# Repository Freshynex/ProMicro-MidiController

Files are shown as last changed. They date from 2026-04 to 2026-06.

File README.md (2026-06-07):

# Pro Micro Midi Controller

## 1. A projekt bemutatása
### 1.1 Általános leírás
Ez a projekt a zenekészítés/zeneszerzés folyamatát segíti a MIDI protokoll felhasználásával.
Ennek a készüléknek a felépítése különböző feladatott ellátó alrészekből áll.

### 1.2 Vezérlő és modulok



A legfőbb része egy Atmel ATMEGA32u4 ic-vel ellátott Arduino Pro Micro fejlesztői alaplap (továbbiakban MCU).
Az MCU-t egy kifejtő-kártyára helyezve a többi alrész (továbbiakban modul) ráköthető.

A kifejtőkártya:

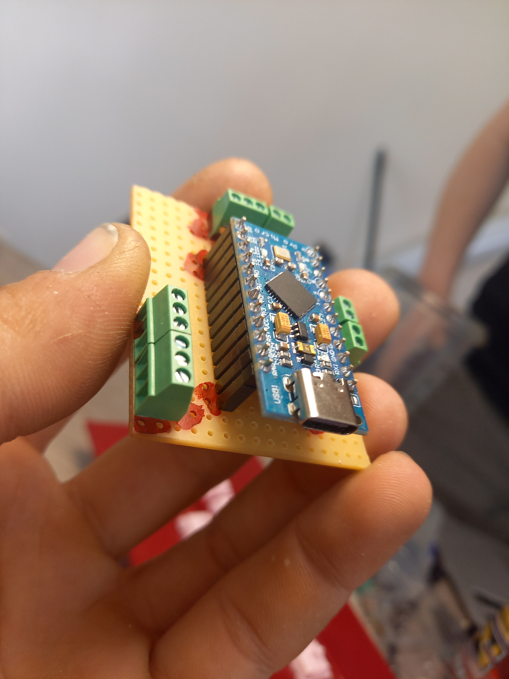
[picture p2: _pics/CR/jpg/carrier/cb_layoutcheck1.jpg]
carrier board


A következő modulok vannak integrálva a készülékben:

 - Kijelző modul (továbbiakban <b>DISP</b>), amely egy egyszerű interfészt biztosít, hogy az aktuális bemeneti
értékeket visszaadja, illetve hogy kényelmesen lehessen konfigurálni azt.

 - Oktáv-váltó modul (továbbiakban <b>OCTSTP</b>), amely egyszerű elérhetőséget ad oktáv-léptetéshez
  
 - Analóg modul (továbbiakban <b>ANAL</b>), egy olyan felület amely kihasználja az MCU saját analog bemeneteit, és
visszaad egy értéket.

 - Billentyűzet modul (továbbiakban <b>KB</b>), amely egy 2 oktávos zongora interfészt ad a felhasználónak. 

## 2. Alkatrészek és kapcsolás

### 2.1 Főalkatrészek

MCU: Arduino Pro Micro Atmel ATMEGA32u4

DISP: 128x64 i2c oled display (SSD1306 driver)

Oktáv váltó gombok: TACTS-6x6x7.3 (2 db)

KB gombok: AKKO Stellar Rose Switch – Lubed-5pin (24 db)

Tengelyes potméter: POM1615 LIN 1K B (2 db)

Toló potméter: PTA2043-2015CIB203 (2 db)

PISO shift register: 74HC166 (3 db)

### 2.1 Kapcsolás rajz

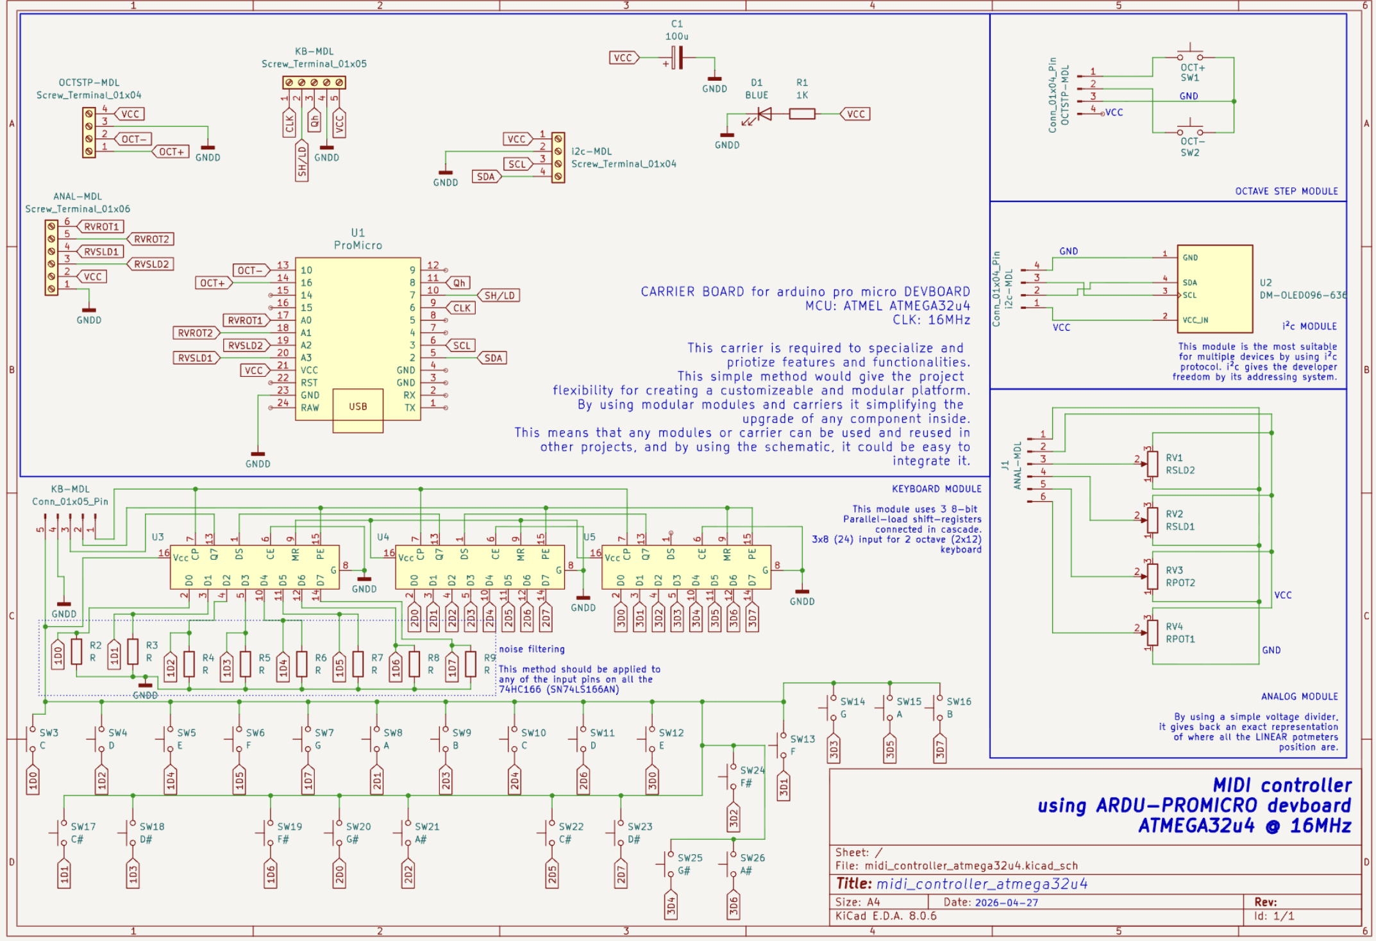
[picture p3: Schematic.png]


## 3. Funkcionalitás
 Teszteléshez használt szoftver: FL Studio 20 (Macbook M1-en kicsit bugos, ezért a kép villódzik néha)

### 3.1 MIDI Protokoll

A MIDI protokollban 8 bites adatcsomagokkal dolgozunk. Két féle üzenet van: status és data. Az első bit azt jelöli, hogy a kettő közül melyiket küldjük, így adat üzenet esetén 0-127, command üzenet esetén 128-255 a használható értéktartomány. Ezek együttesen alkotnak egy midi üzenetet (message).

Egy üzenet mindig status byte-tal kezdődik, amit a parancs függvényében 0, 1 vagy 2 data byte követ.
A status byte felső 4 bitje jelöli a kiadott parancsot (aminek az első bitje mindig 1, így az első kódszó decimálisan a 8), a második fele a csatornát jelöli (16 csatornát lehet kezelni, ebben a projektben egynél többre nincs szükségünk).

Számunkra fontosabb status üzenetek:

| Status üzenet  | Üzenet kódja | Adat byte 1 | Adat byte 2 | Adat byte 3 |
| ---  | --- | --- | --- | --- |
| NoteOn | 0x90 | Pitch | Velocity | |
| NoteOff | 0x80 | Pitch | Velocity | |
| Control Change | 0xB0 | CC number | MSB | LSB * | 

 *<sub> Adat byte 3 (LSB) nem kötelező, de 7 helyett 14 bit pontosságu értéket adhatunk meg vele </sub>

### 3.2 Billentyűzet
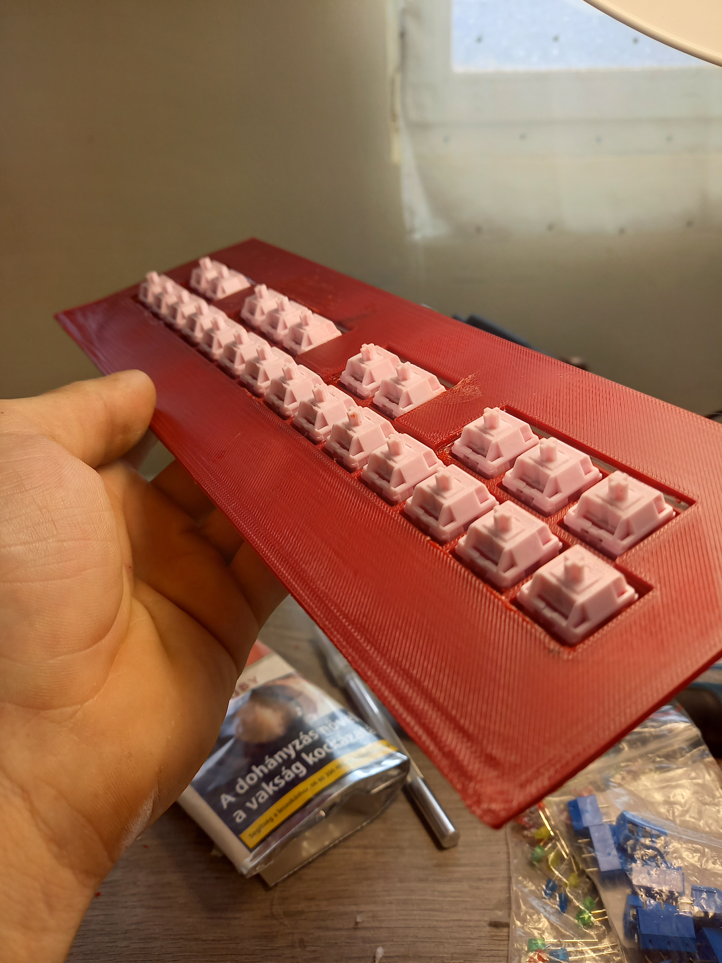
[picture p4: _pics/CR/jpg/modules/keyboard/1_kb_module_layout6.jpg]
Keyboard

A billentyűzet kialakítása egy zongora mintájára készült. 2 oktáv, ami 24 gomb. A gombok mechanikus billentyűkapcsolókkal vannak kivitelezve. A keret illetve gomb kupakok 3D nyomtatással készültek. Három kaszkádolt parallel in serial out shift register segítségével vannak az MCU-ra kötve, így csak 3 pin felhasználása szükséges. Ez a fajta megoldás lehetővé teszi hogy 3Byte-on visszakapjuk a gombok állapotát egyszerre.

### 3.3 Oktáv váltás
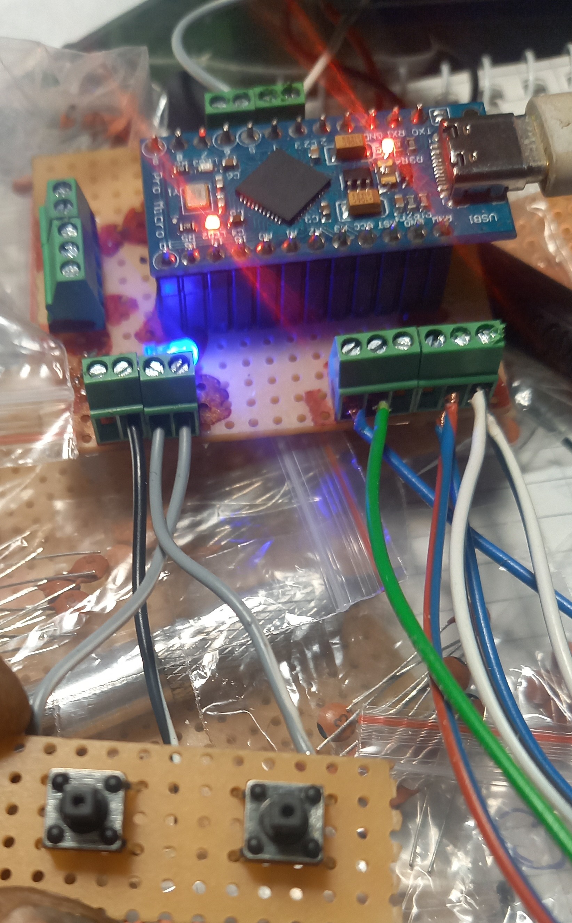
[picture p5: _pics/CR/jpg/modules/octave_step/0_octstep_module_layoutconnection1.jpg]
Octave buttons

A zenekészítéshez szükséges, hogy a billentyűzet képes legyen több oktávon is játszani. Ehhez az <b>MCU</b> két digitális bemenetét használjuk. A készülék oktáv-váltó gombok hatására a billentyűzeten reprezentált 2 oktávot eltolja, és így mind a 10 MIDI protokollban használt oktáv elérhető.

### 3.4 Analog bevitel
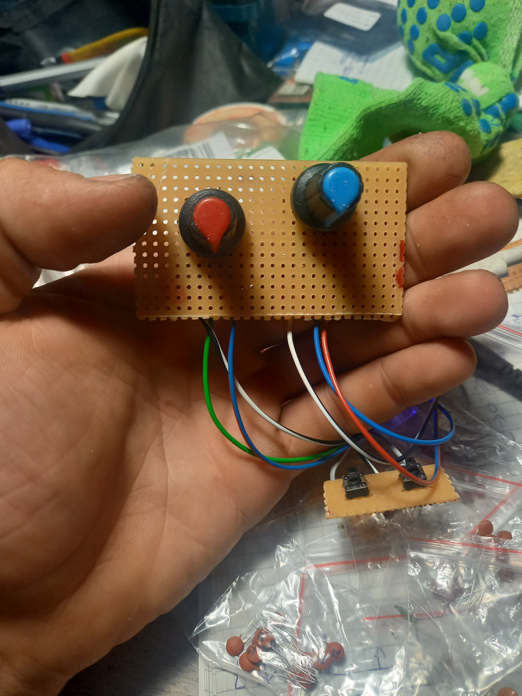
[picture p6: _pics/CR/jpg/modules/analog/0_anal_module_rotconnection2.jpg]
Potmeters

Kettő forgatható és kettő tolható lineáris potméter segítségével, kihasználva Kirchoff törvényeit, képes a készülék adott csatornák állapotait módosítani. A választott <b>MCU</b> analog bemenetei a referencia feszültséghez képest adja vissza a bemeneti értéket. Ezt a készülék 0-1023-as intervallumban elhelyezi (map-eli).

Ez a következő képpen nyílvánul meg:
| Ref. V | ANAL bemenet | Érték |
| ---  | --- | --- |
| 5V | 0V | 0 |
| -"- | 2.5V | 512 |
| -"- | 5V | 1023 |

### 3.5 i²c Kijelző és protokol

Az i²c, egy olyan protokoll, amely MASTER-SLAVE kapcsolatot biztosít <u>kettő vagy több</u> eszköz között. A szállítandó adatot a protokoll címkézi és szállítja az adatvonalon.
Amikor a SLAVE címe egyezik a csomagban elhelyezett célcímmel, akkor azt a SLAVE fogadja és feldogozza. 

A készülék rendelkezik egy kis 1.2"-es OLED kijelző, amely SSD1306-os meghajtású. Jelenleg a <b>DISP</b> beépített címmel rendelkezik, amelynek a módosítása nehézkes.
A mostani címe <b>0x78</b>.

## 4. Bővithetőség
### 4.1 I²C (Inter-Integrated Circuit)

Az <b>MCU</b>-nak nem az összes pin-jét használtuk, ezért ezekre még kapcsolhatóak eszközök. Amennyiben a beépítendő eszköz i²c-vel kommunikál, így az ráközhető párhuzamosan ugyanarra az ágra, amelyiken rajta van a <b>DISP</b>. Ebben az esetben érdemes figyelni a rákötendő eszköz <u><b>címére</b></u>. Amennyiben a címeknél ütközés történik, úgy nem fog működik a ráhelyezett eszköz, illetve a <b>DISP</b>.

Lehetséges bővítési lehetőségek a jelzett protokollon:
| IC / MODUL név | Funkció |
| ---  | --- |
|  ADS1115 / -M  | ANAL bővítő (A0 - A3) |
|PCF8574 / IN830S| DIGITAL bővítő (8db, be) |
|PCF8574 / OC805S| DIGITAL bővítő (8db, ki) |

### 4.2 UART (Universal Asynchronous Receiver-Transmitter)

Az UART egy olyan soron protokoll fajta, amely két egyenrangú eszközt köt össze. Bekötéséhez egy adó, egy fogadó és közös test szükséges. Ez a protokoll a közlendő információt egy start- és stop-bittel ellátott bitfolyammá alakítja.
Ehhez a fajta kapcsolathoz nem szükséges külön órajel, mivel a kommunikációt egy közösen előre deklarált jelaránnyal (baudrate) éri el. A Küldő fél a bitfolyamot a saját Tx (Transmit) ágán küldi a másik eszköz Rx (Receive lábára.
Ez igaz fordítottan is, ezért ez a fajta megoldás Full-Duplex-nek minősül.
| A eszköz | B eszköz |
|---|---|
| Tx | Rx |
| Rx | Tx |
| G | G |
| *Vcc | *Vcc |

*<sub>Ha a másik készülék rendelkezik saját táp-ellátással, akkor a Vcc összekötése nem szükséges.</sub>

## 5. Készülék Prezentáció és Demo

### Billentyűzet
https://github.com/user-attachments/assets/6a722bac-2a85-4638-812b-2556ad7aba79

### Potméter
[<video src="_vids/Pot_demo.mp4" width="320" height="240" controls></video>
](https://github.com/user-attachments/assets/77403d33-6a48-4602-aa05-ce928a655359
)
### Billentyűzet, potméter (pitch paraméter állítása), oktáv váltás
https://github.com/user-attachments/assets/33ad1122-0a03-4d51-aa62-576f443cc43e

### 3D render

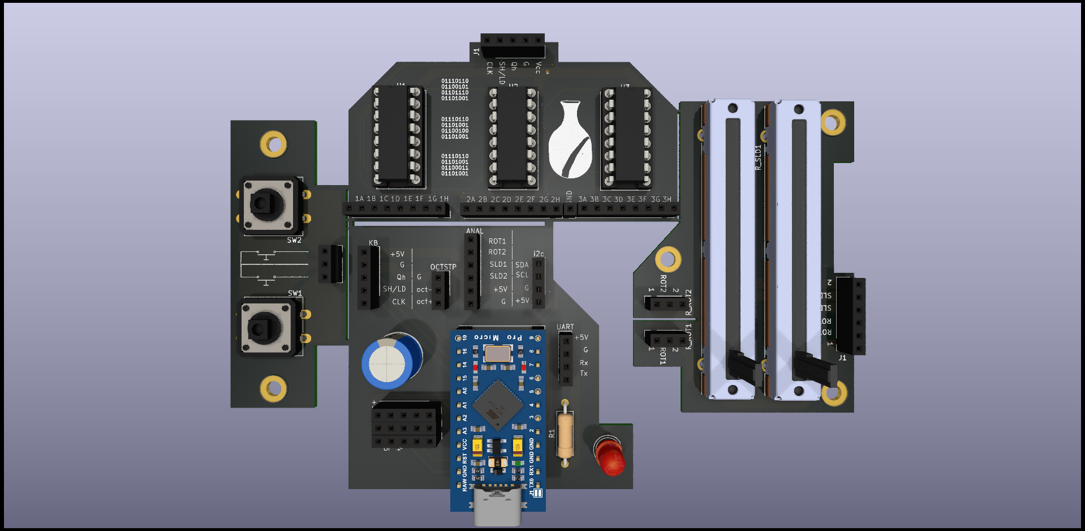
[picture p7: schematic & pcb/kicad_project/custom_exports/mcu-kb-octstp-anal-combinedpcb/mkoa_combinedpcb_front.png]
mkoa_front

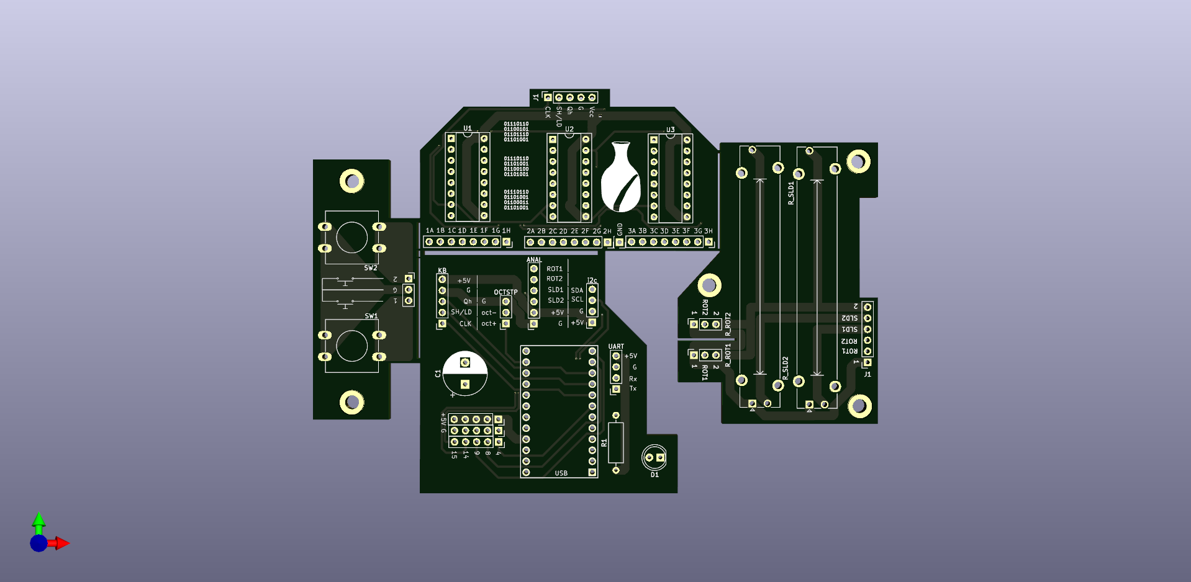
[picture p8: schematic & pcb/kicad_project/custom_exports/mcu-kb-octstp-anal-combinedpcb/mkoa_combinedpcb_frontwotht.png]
mkoa_front2

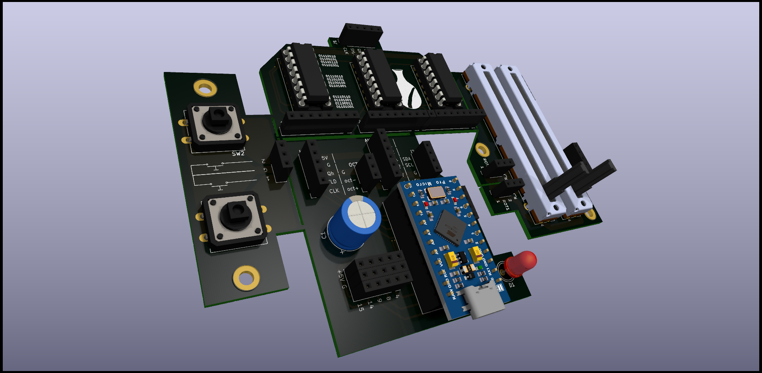
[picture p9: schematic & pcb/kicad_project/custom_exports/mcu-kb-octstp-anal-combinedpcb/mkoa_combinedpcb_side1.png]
mkoa_side1

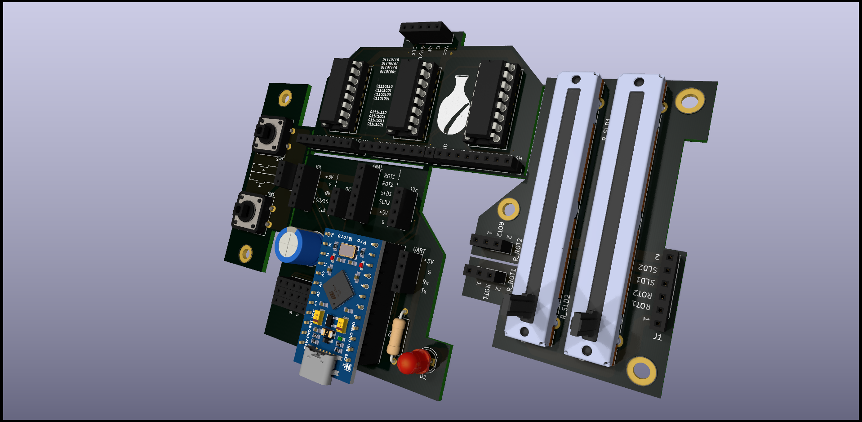
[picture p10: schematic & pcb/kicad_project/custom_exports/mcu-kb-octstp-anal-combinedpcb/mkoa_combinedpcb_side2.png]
mkoa_side2


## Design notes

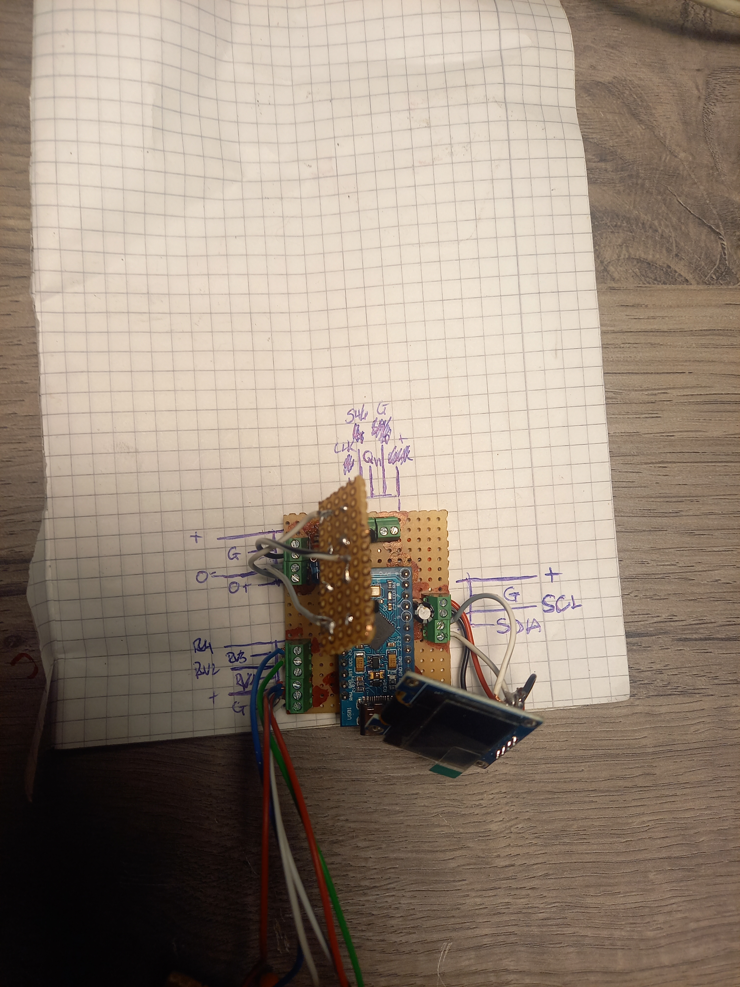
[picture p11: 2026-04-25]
_pics/CR/jpg/carrier/prjct_pinout1.jpg

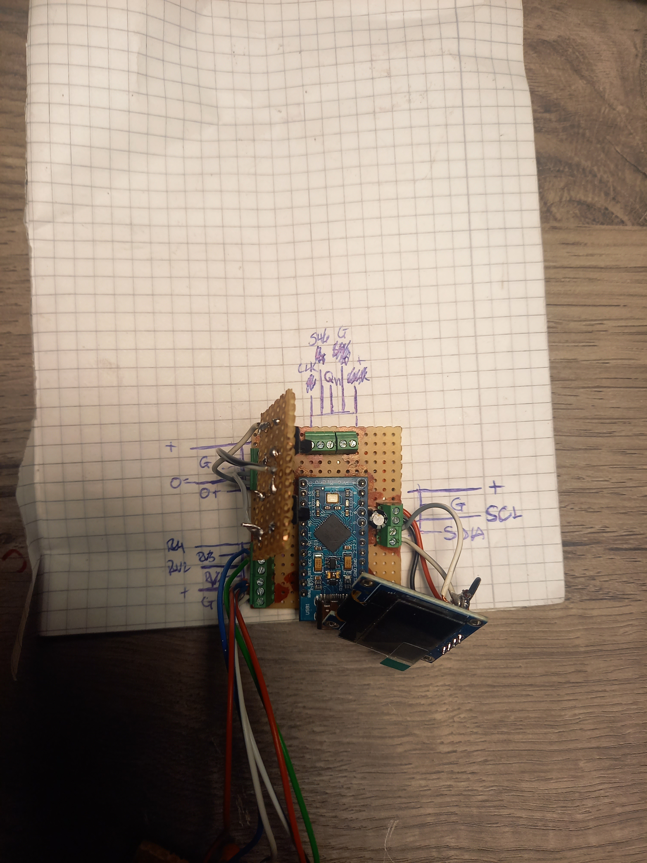
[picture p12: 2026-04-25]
_pics/CR/jpg/carrier/prjct_pinout2.jpg

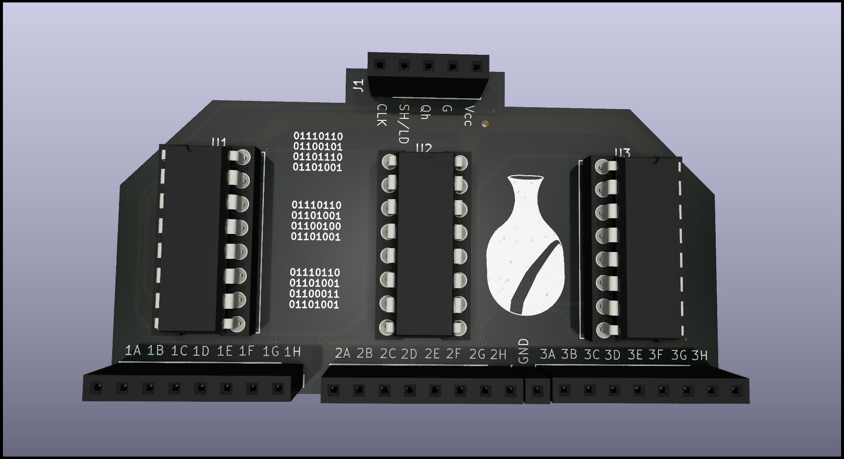
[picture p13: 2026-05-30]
schematic & pcb/exports/kb_3d_3.jpeg

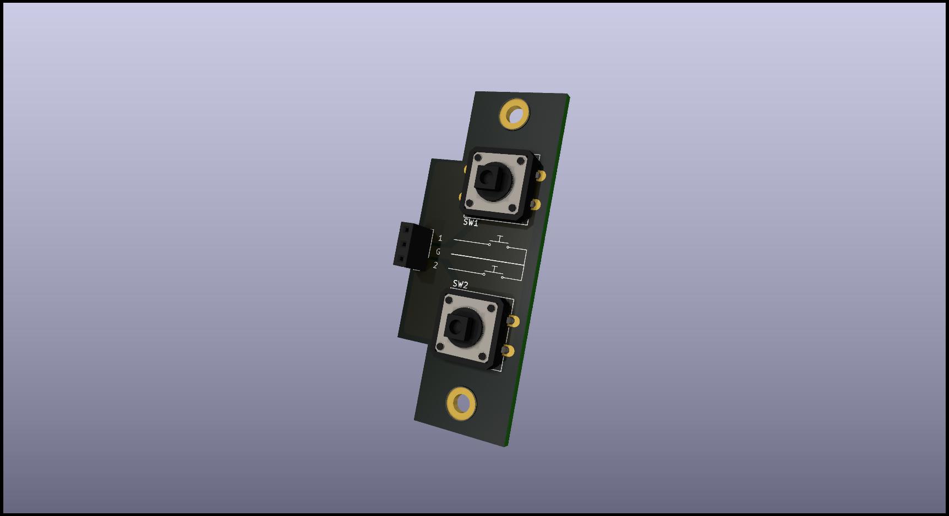
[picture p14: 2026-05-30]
schematic & pcb/exports/octstp_3d_2.jpg

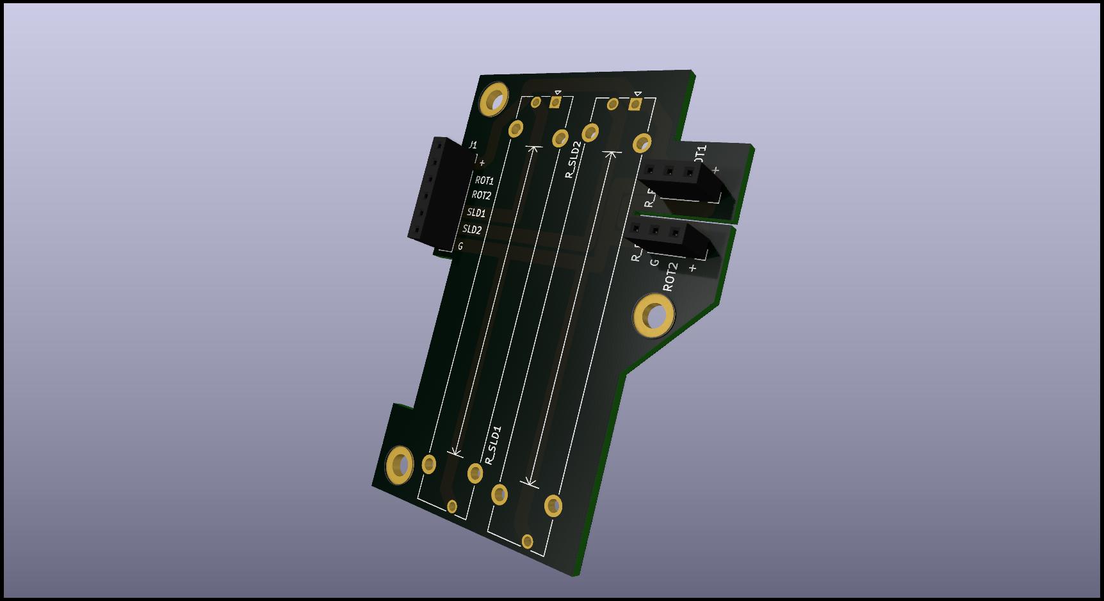
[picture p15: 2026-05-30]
schematic & pcb/exports/anal_3d_2.jpg

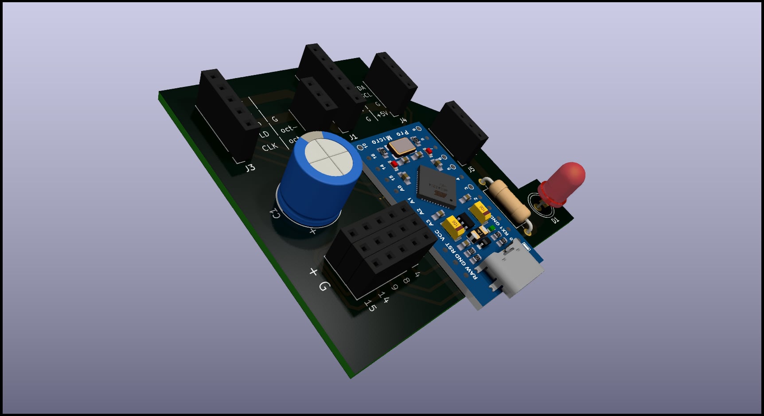
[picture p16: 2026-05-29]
schematic & pcb/exports/carrier_3d_2.jpeg

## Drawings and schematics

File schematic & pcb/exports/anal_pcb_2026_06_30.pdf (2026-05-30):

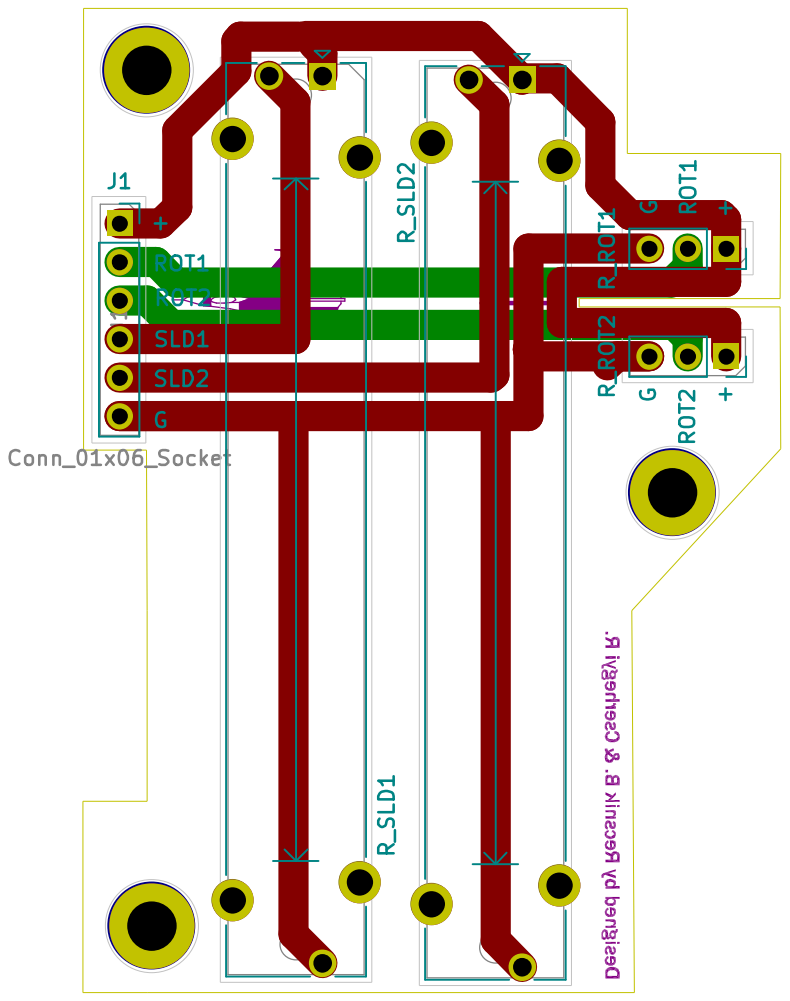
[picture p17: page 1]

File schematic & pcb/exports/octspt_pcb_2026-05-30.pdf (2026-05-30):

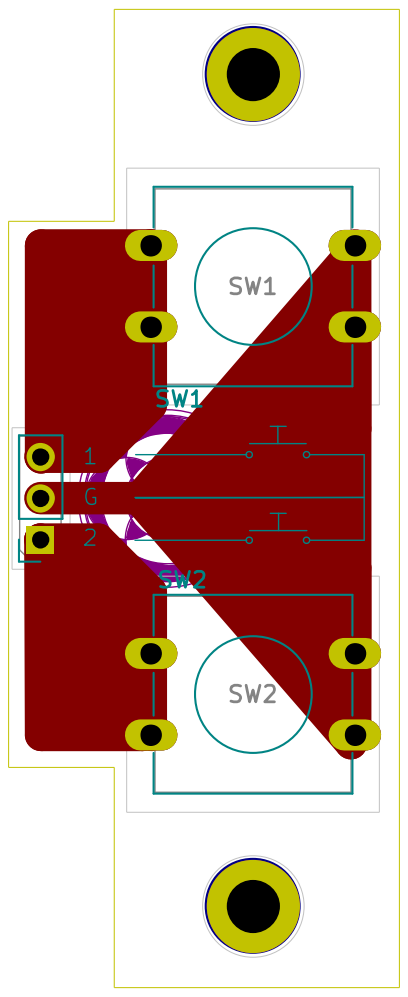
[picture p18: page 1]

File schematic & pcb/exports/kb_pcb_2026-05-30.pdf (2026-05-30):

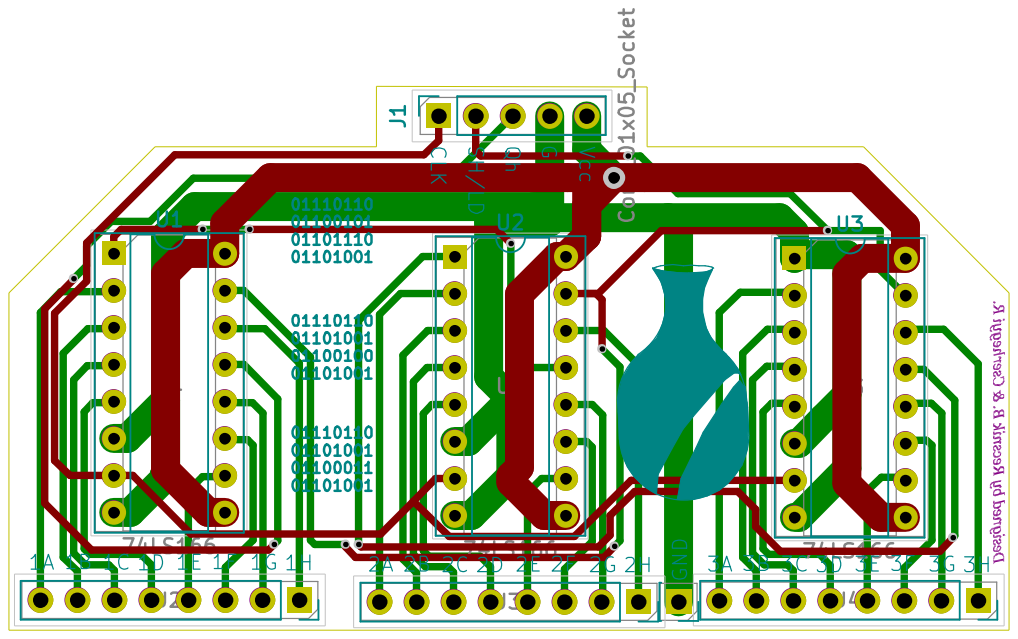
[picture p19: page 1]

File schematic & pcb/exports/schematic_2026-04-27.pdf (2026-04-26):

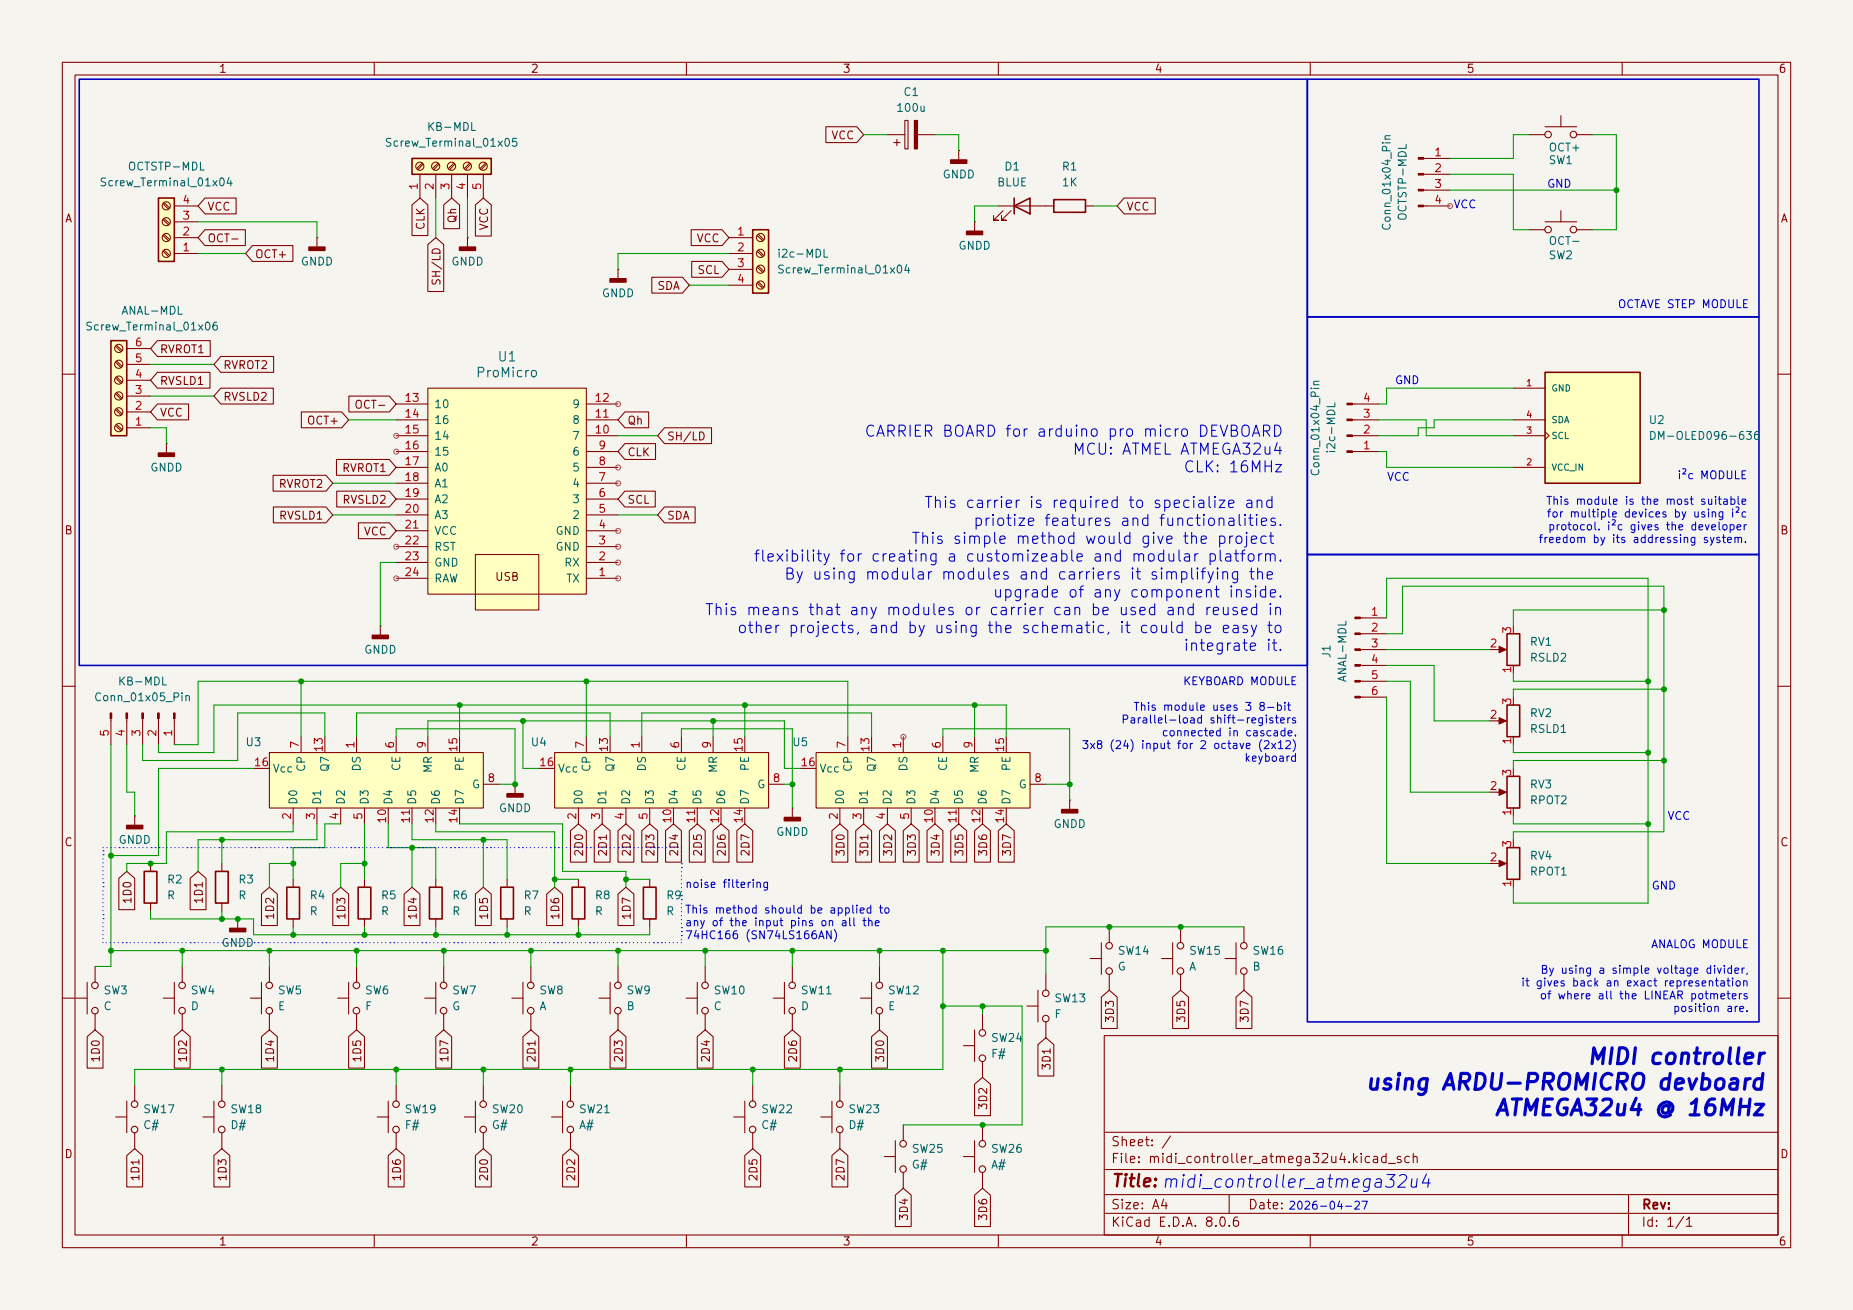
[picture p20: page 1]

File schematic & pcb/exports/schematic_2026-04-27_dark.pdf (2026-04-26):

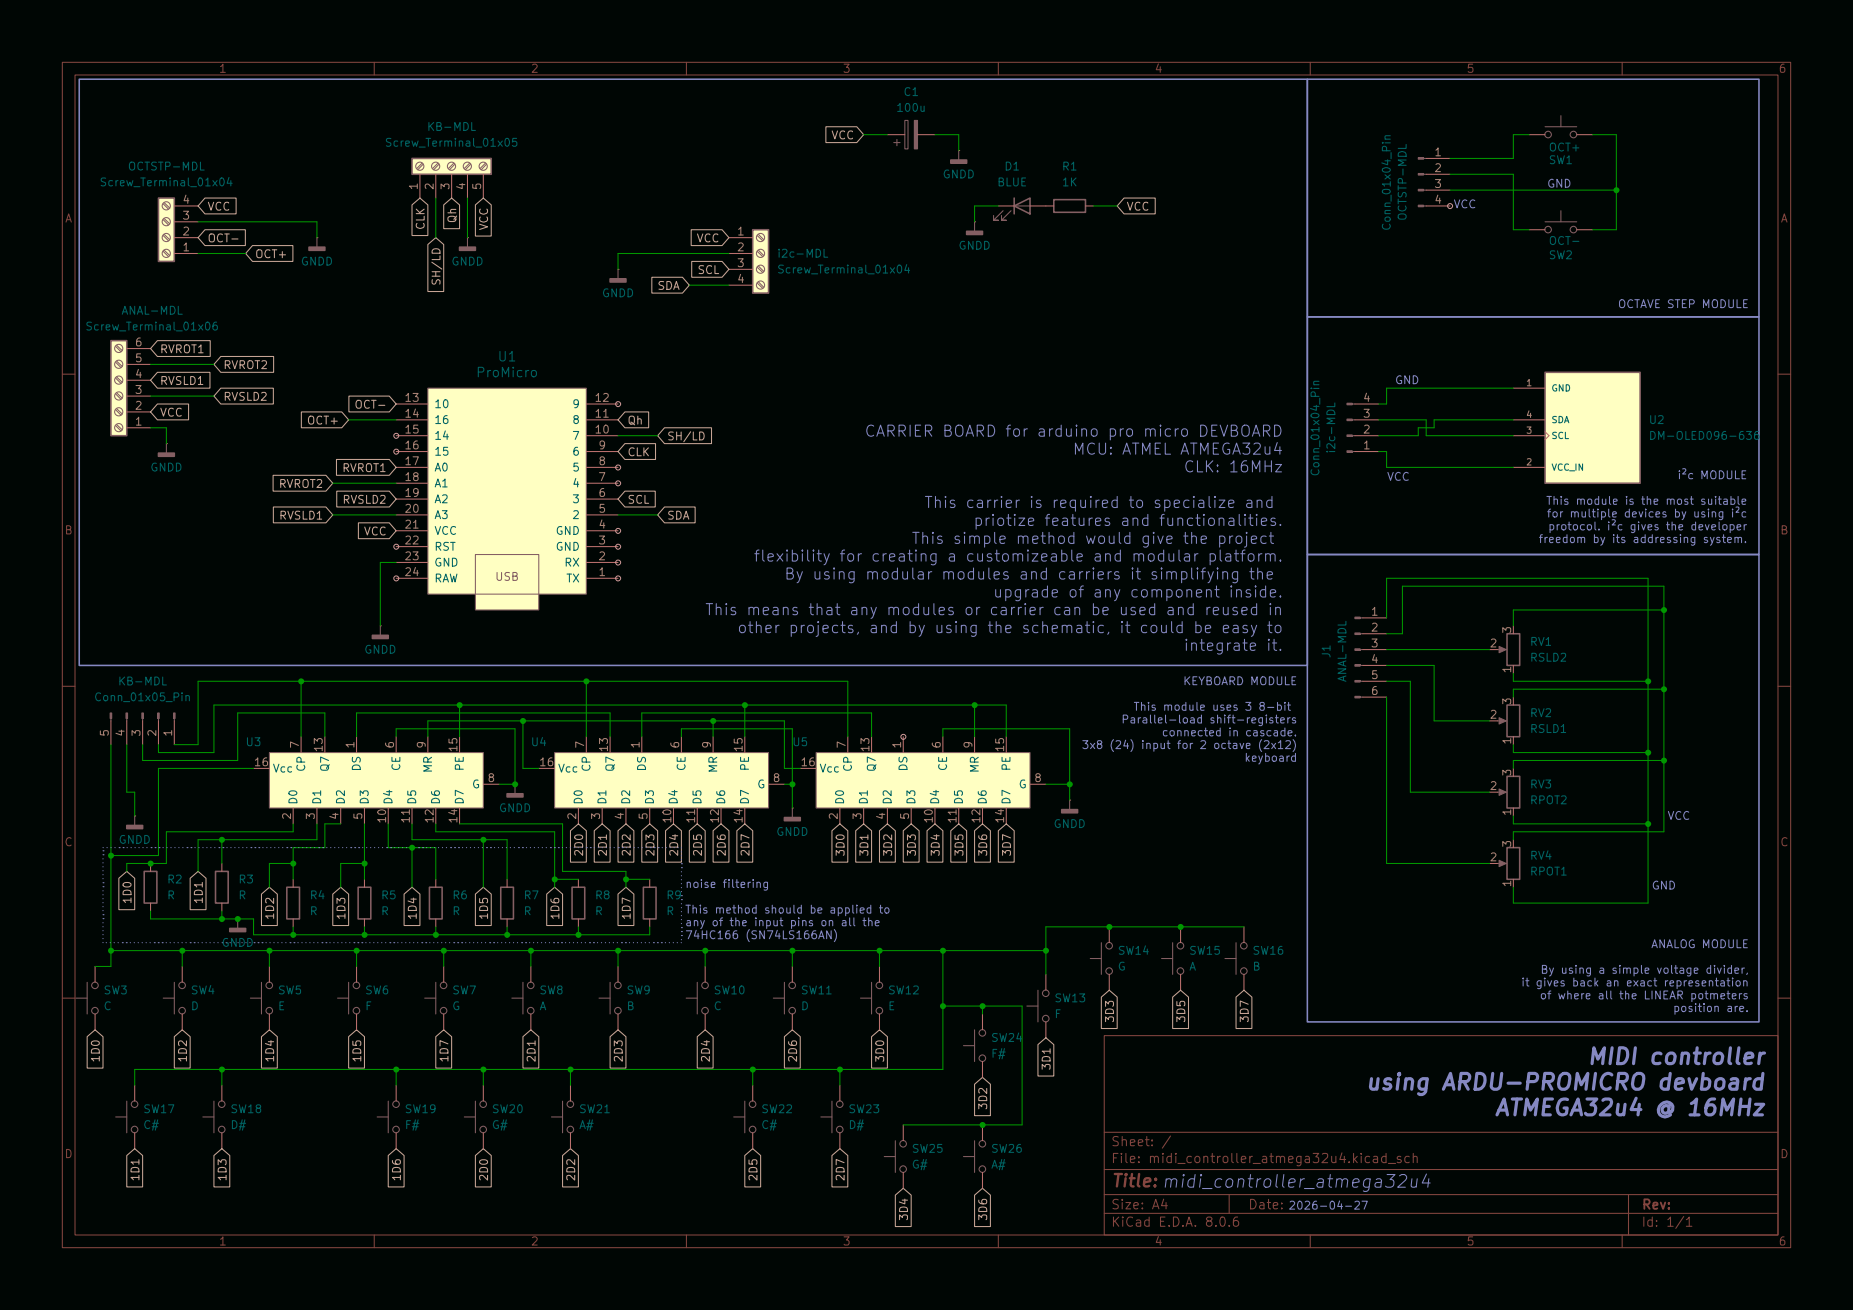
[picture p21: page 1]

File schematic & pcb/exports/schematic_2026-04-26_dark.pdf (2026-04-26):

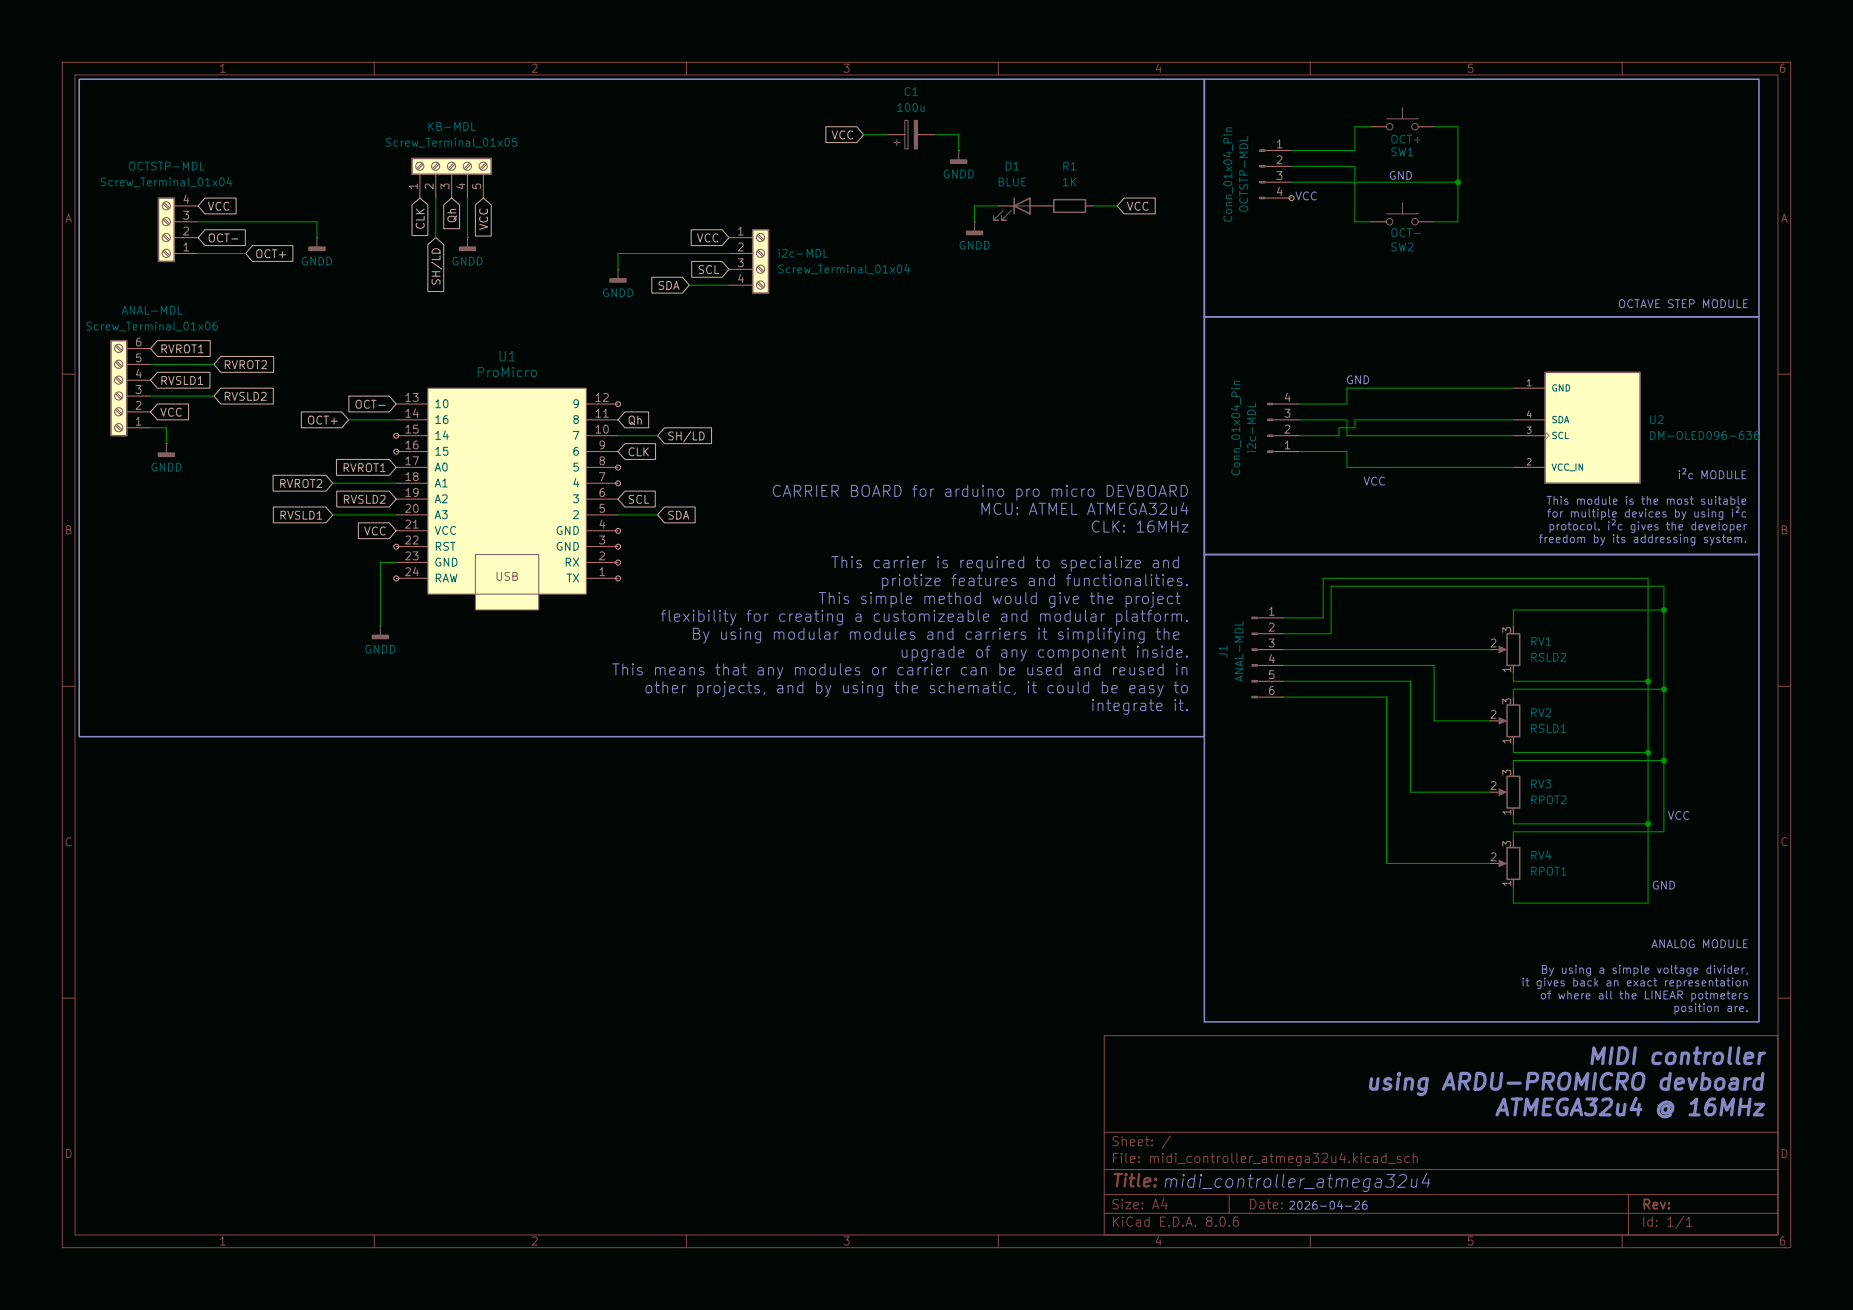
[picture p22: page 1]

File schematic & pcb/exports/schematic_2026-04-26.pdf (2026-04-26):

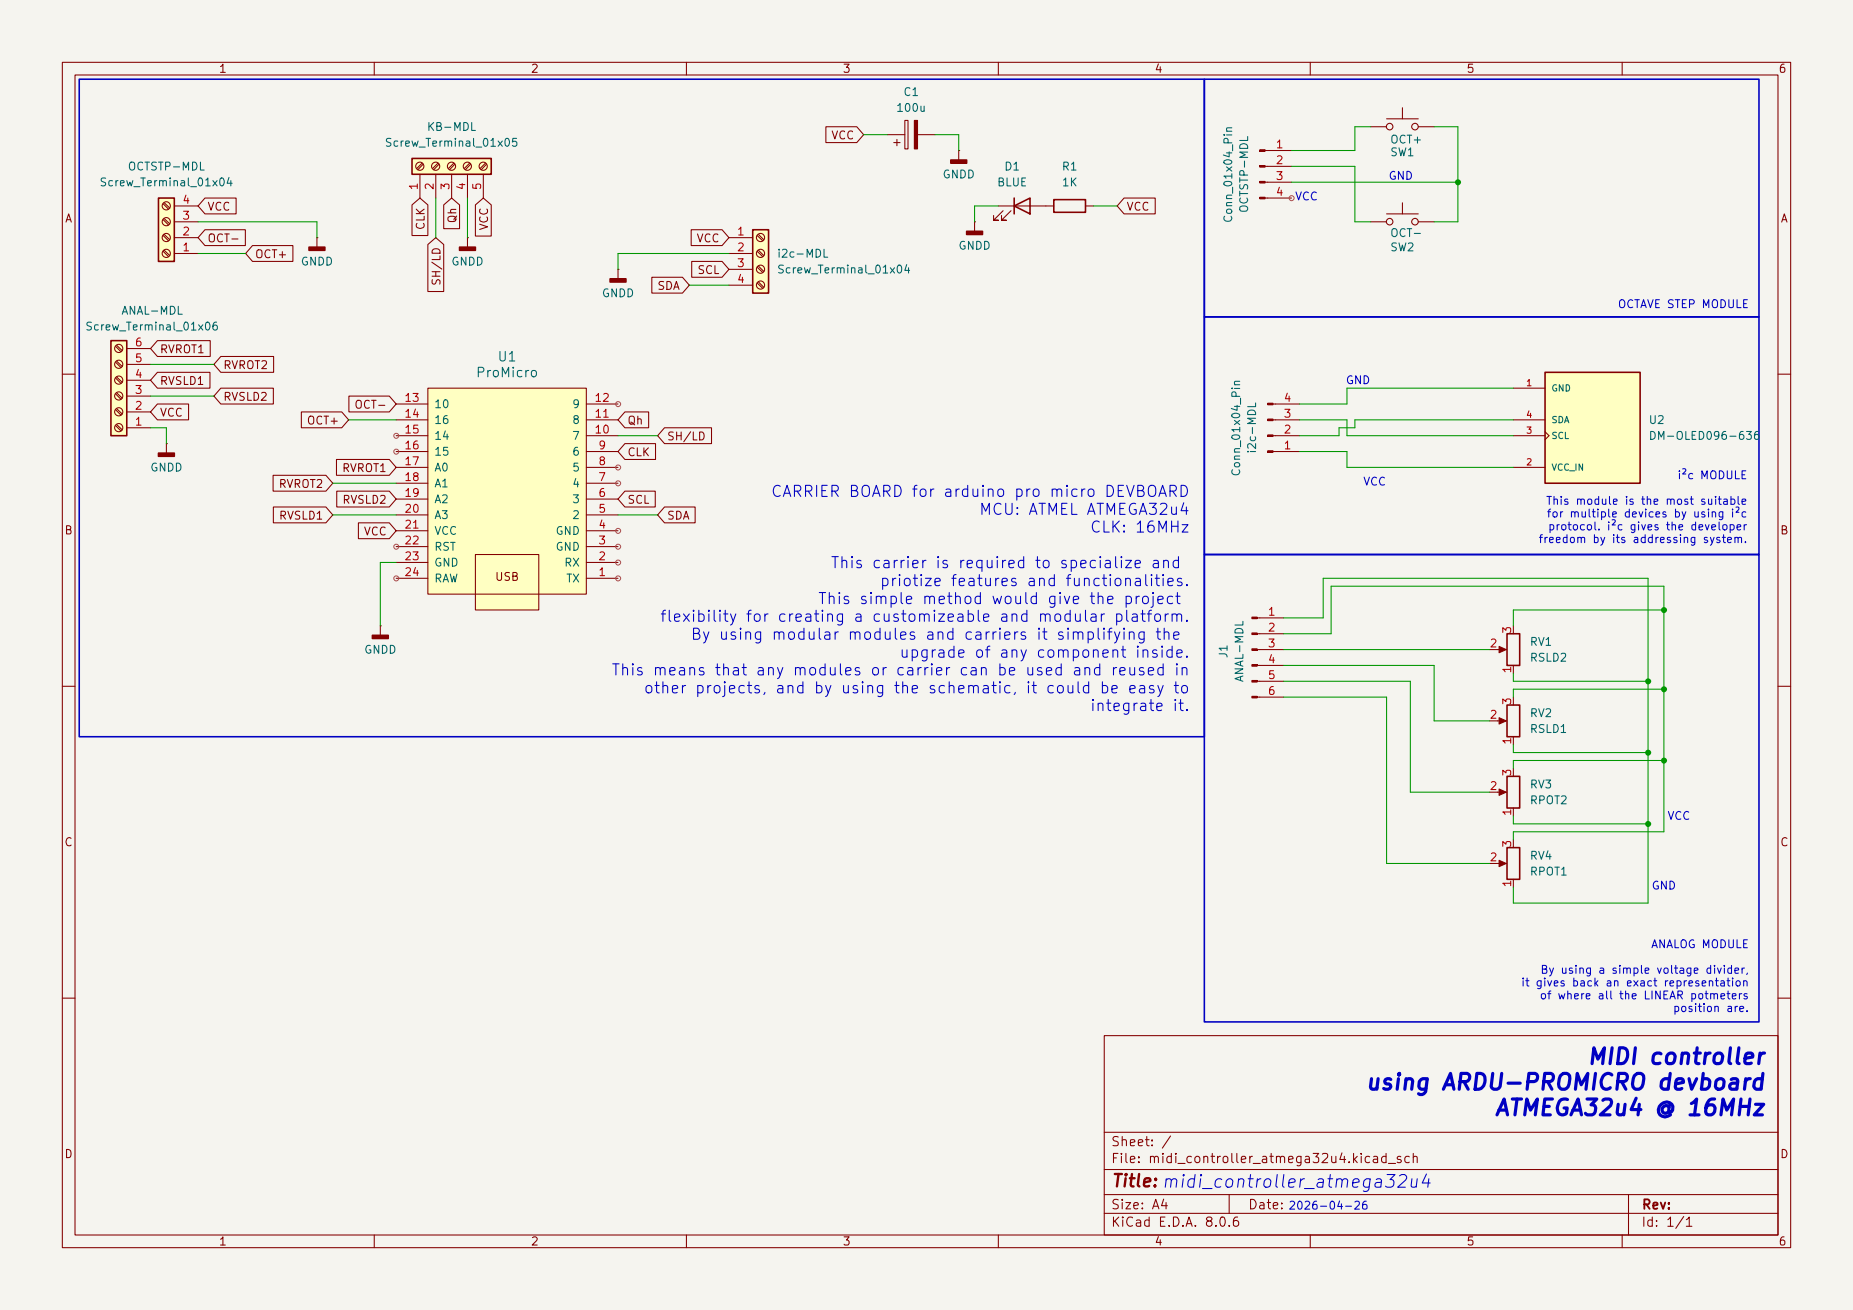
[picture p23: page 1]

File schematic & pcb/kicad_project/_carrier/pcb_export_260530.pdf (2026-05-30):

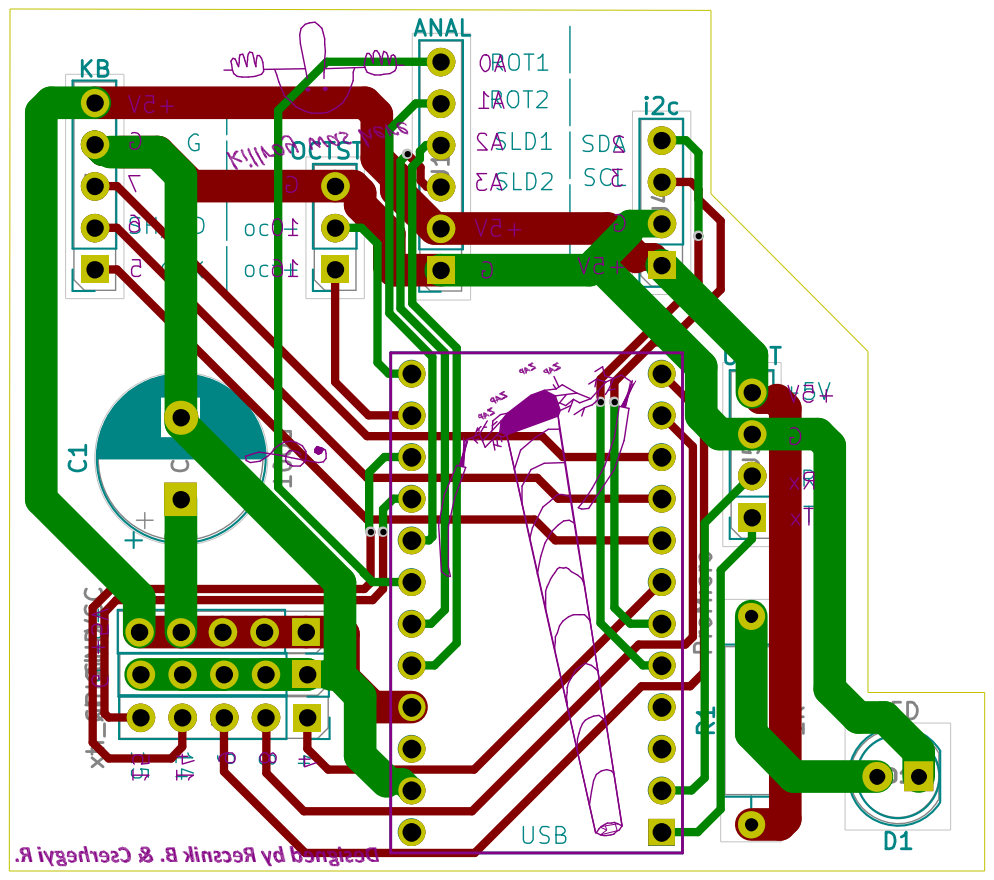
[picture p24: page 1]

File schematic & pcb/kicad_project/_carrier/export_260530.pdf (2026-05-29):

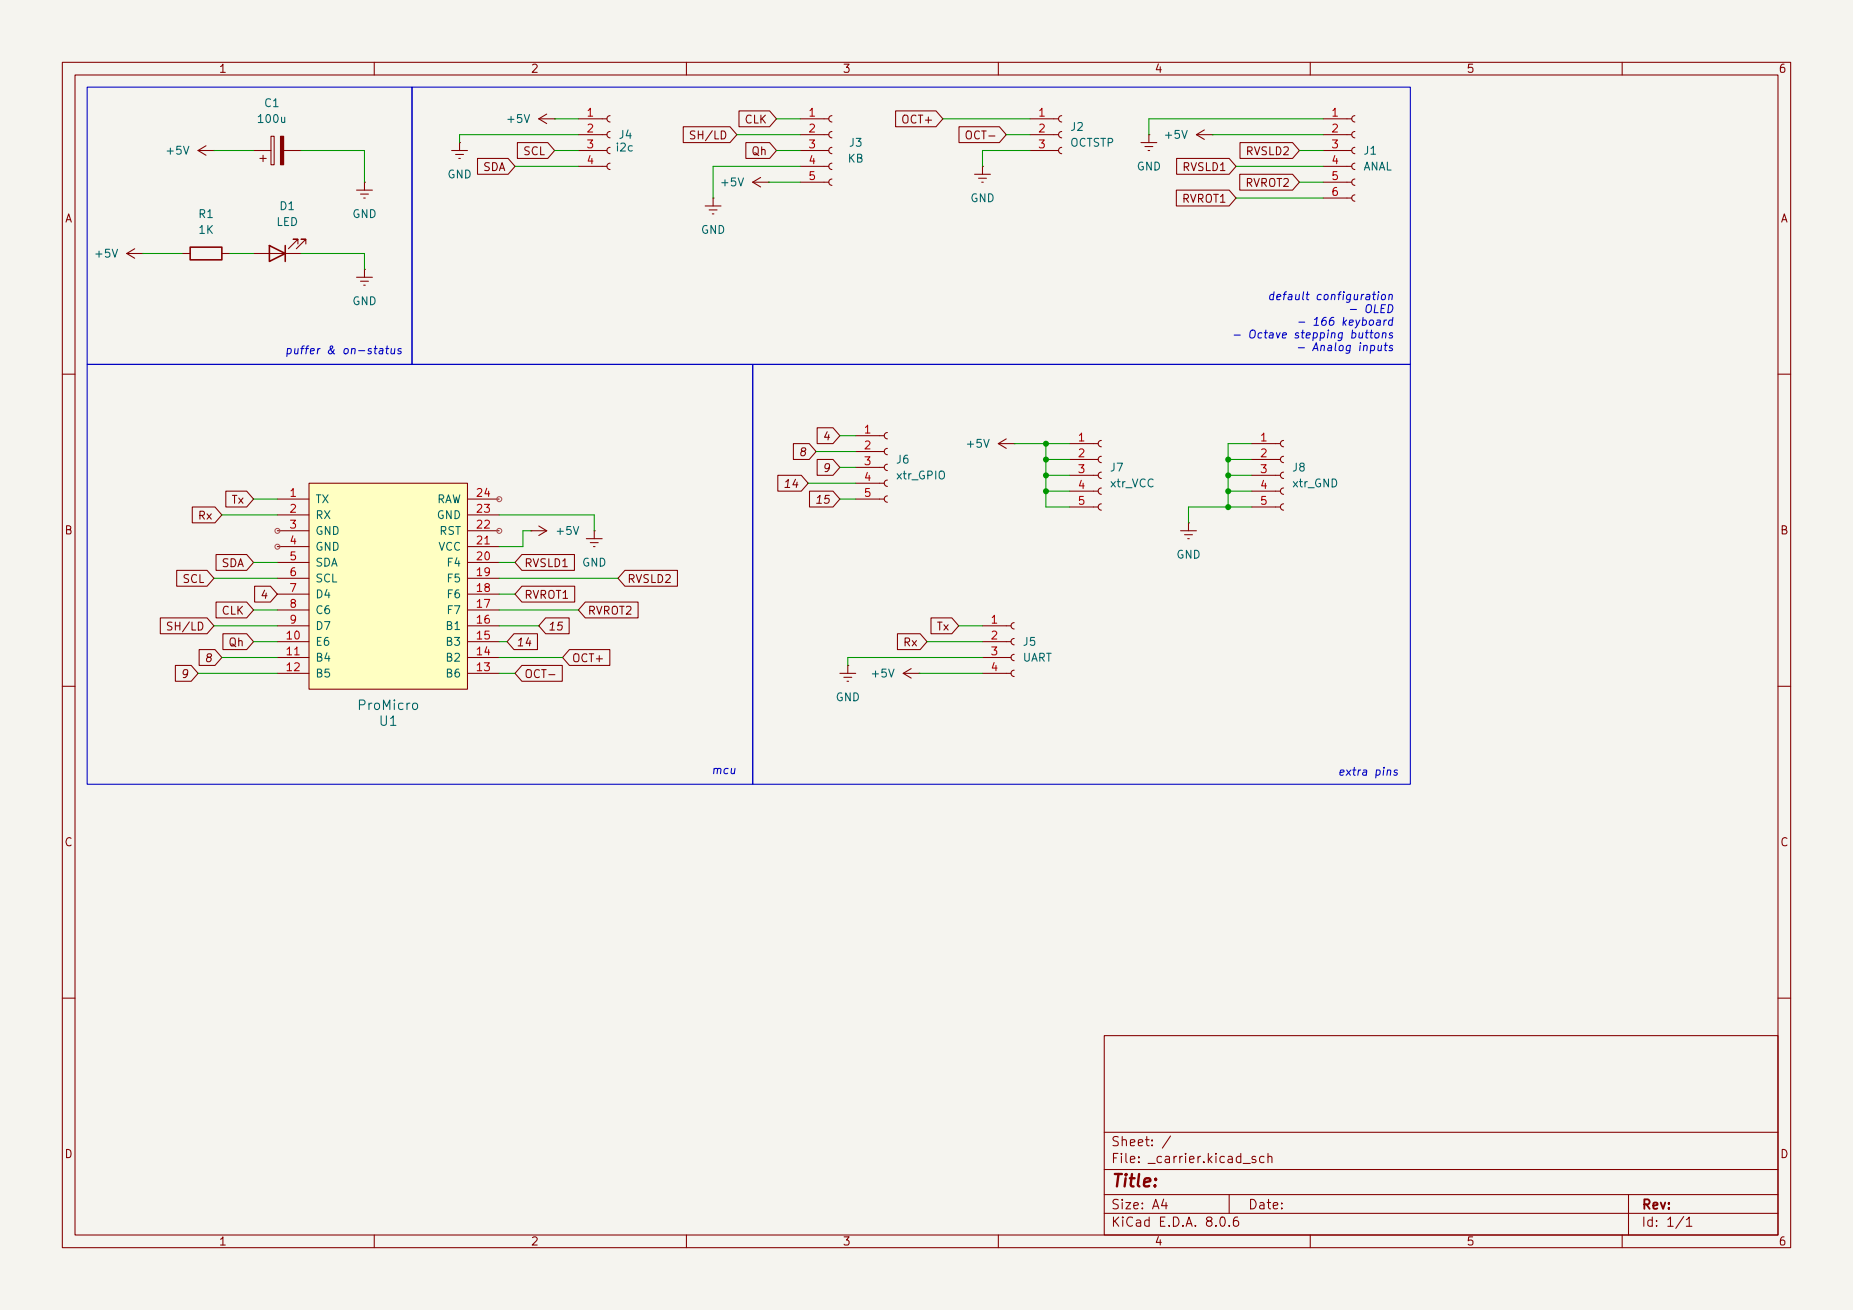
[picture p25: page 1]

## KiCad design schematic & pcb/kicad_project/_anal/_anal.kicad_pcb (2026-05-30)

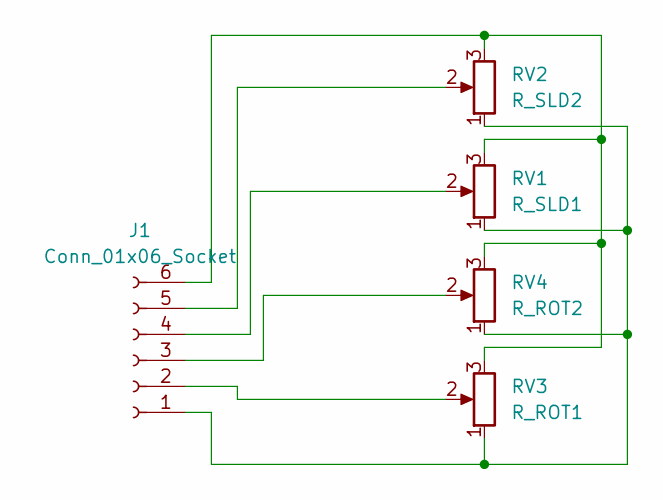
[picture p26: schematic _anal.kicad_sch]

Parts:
J1: Conn_01x06_Socket; PinSocket_1x06_P2.54mm_Vertical
RV1: R_SLD1; Potentiometer_Bourns_PTA4543_Single_Slide
RV2: R_SLD2; Potentiometer_Bourns_PTA4543_Single_Slide
RV3: R_ROT1; PinSocket_1x03_P2.54mm_Vertical
RV4: R_ROT2; PinSocket_1x03_P2.54mm_Vertical

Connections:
unnamed: J1.1, RV1.1, RV2.1, RV3.1, RV4.1
unnamed: J1.2, RV3.2
unnamed: J1.3, RV4.2
unnamed: J1.4, RV1.2
unnamed: J1.5, RV2.2
unnamed: J1.6, RV1.3, RV2.3, RV3.3, RV4.3

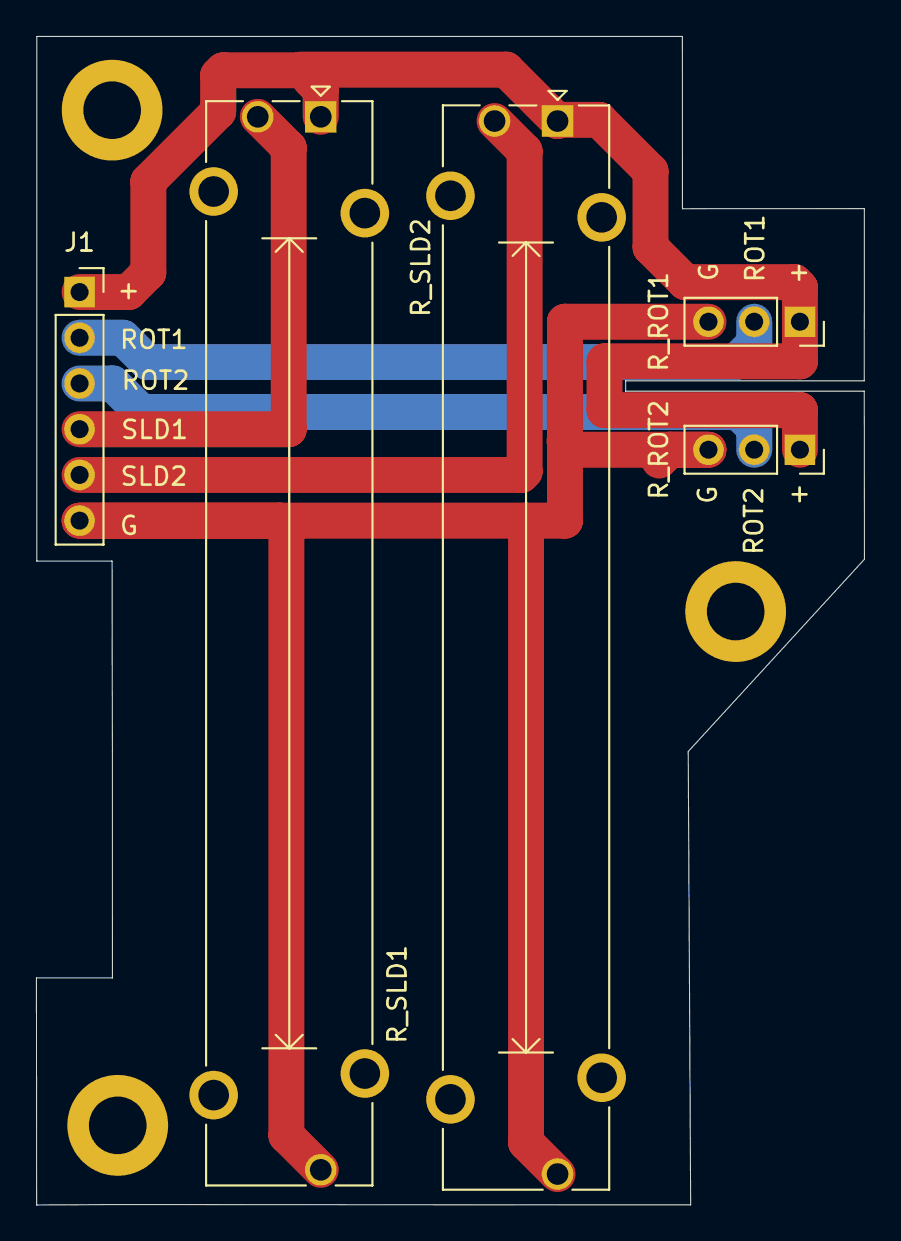
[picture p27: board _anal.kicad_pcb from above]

Board: 2 copper layers, 46.0 x 64.9 mm, 5 parts (0 on the bottom side), 6 nets.

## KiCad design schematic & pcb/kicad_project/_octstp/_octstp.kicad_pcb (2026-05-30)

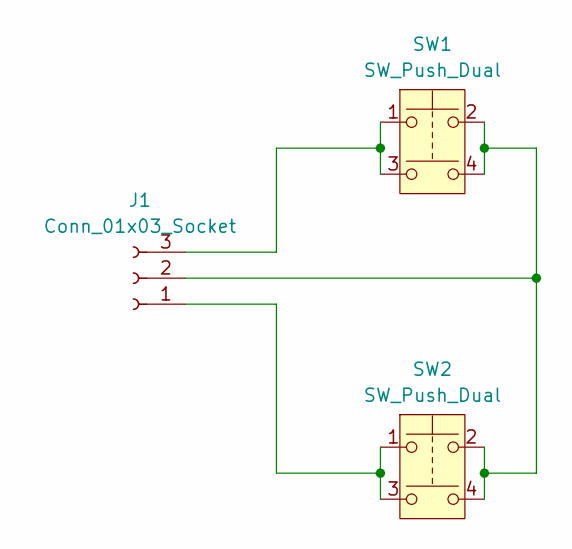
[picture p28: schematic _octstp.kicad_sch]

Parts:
J1: Conn_01x03_Socket; PinSocket_1x03_P2.54mm_Vertical
SW1, SW2: SW_Push_Dual; SW_PUSH-12mm

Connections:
unnamed: J1.1, SW2.1, SW2.3
unnamed: J1.2, SW1.2, SW1.4, SW2.2, SW2.4
unnamed: J1.3, SW1.1, SW1.3

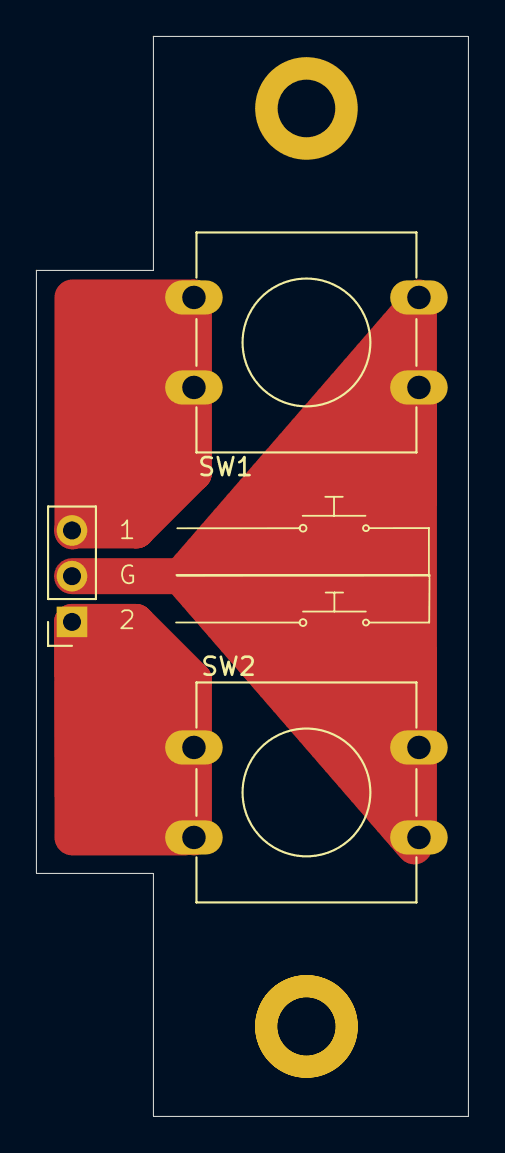
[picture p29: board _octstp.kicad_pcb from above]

Board: 2 copper layers, 24.0 x 60.0 mm, 3 parts (0 on the bottom side), 3 nets.

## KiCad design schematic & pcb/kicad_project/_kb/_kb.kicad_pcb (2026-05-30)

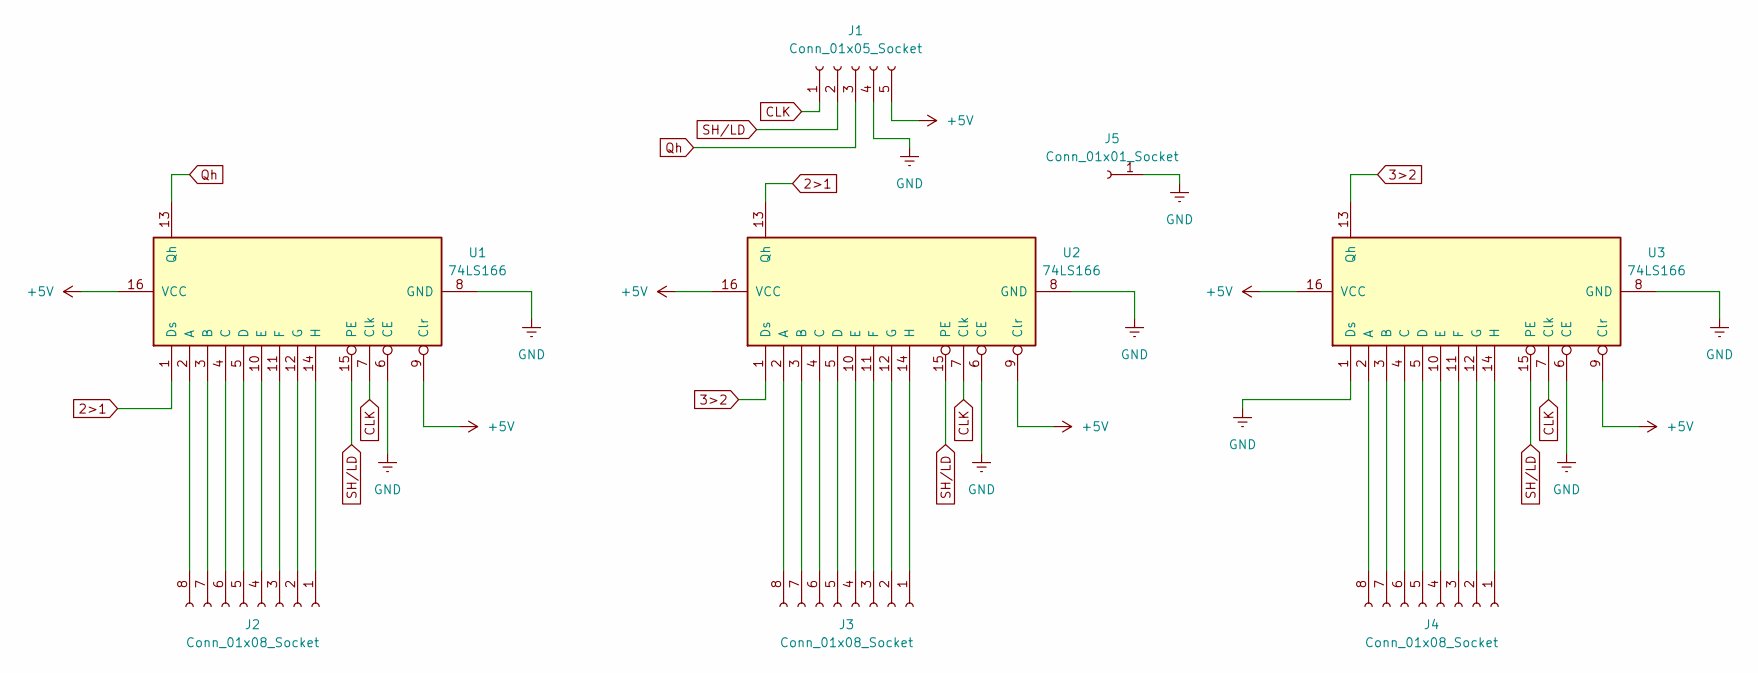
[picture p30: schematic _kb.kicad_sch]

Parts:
J1: Conn_01x05_Socket; PinSocket_1x05_P2.54mm_Vertical
J2, J3, J4: Conn_01x08_Socket; PinSocket_1x08_P2.54mm_Vertical
J5: Conn_01x01_Socket; PinSocket_1x01_P2.54mm_Vertical
U1, U2, U3: 74LS166; DIP-16_W7.62mm_Socket

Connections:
2>1: U1.1 (Ds), U2.13 (Qh)
3>2: U2.1 (Ds), U3.13 (Qh)
+5V: J1.5, U1.9 (Clr), U1.16 (VCC), U2.9 (Clr), U2.16 (VCC), U3.9 (Clr), U3.16 (VCC)
CLK: J1.1, U1.7 (Clk), U2.7 (Clk), U3.7 (Clk)
GND: J1.4, J5.1, U1.6 (CE), U1.8 (GND), U2.6 (CE), U2.8 (GND), U3.1 (Ds), U3.6 (CE), U3.8 (GND)
unnamed: J2.1, U1.14 (H)
unnamed: J2.2, U1.12 (G)
unnamed: J2.3, U1.11 (F)
unnamed: J2.4, U1.10 (E)
unnamed: J2.5, U1.5 (D)
unnamed: J2.6, U1.4 (C)
unnamed: J2.7, U1.3 (B)
unnamed: J2.8, U1.2 (A)
unnamed: J3.1, U2.14 (H)
unnamed: J3.2, U2.12 (G)
unnamed: J3.3, U2.11 (F)
unnamed: J3.4, U2.10 (E)
unnamed: J3.5, U2.5 (D)
unnamed: J3.6, U2.4 (C)
unnamed: J3.7, U2.3 (B)
unnamed: J3.8, U2.2 (A)
unnamed: J4.1, U3.14 (H)
unnamed: J4.2, U3.12 (G)
unnamed: J4.3, U3.11 (F)
unnamed: J4.4, U3.10 (E)
unnamed: J4.5, U3.5 (D)
unnamed: J4.6, U3.4 (C)
unnamed: J4.7, U3.3 (B)
unnamed: J4.8, U3.2 (A)
Qh: J1.3, U1.13 (Qh)
SH/LD: J1.2, U1.15 (PE), U2.15 (PE), U3.15 (PE)

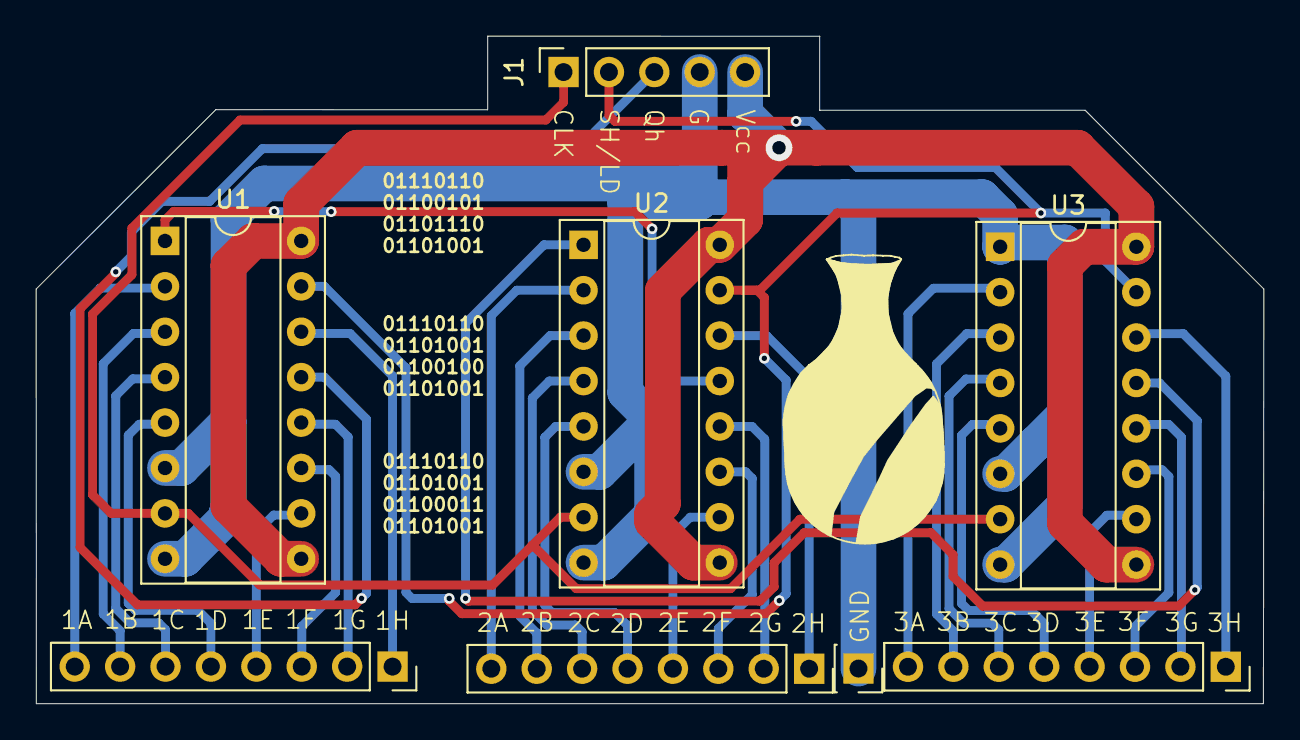
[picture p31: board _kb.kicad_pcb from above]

Board: 2 copper layers, 68.7 x 37.3 mm, 8 parts (0 on the bottom side), 31 nets.

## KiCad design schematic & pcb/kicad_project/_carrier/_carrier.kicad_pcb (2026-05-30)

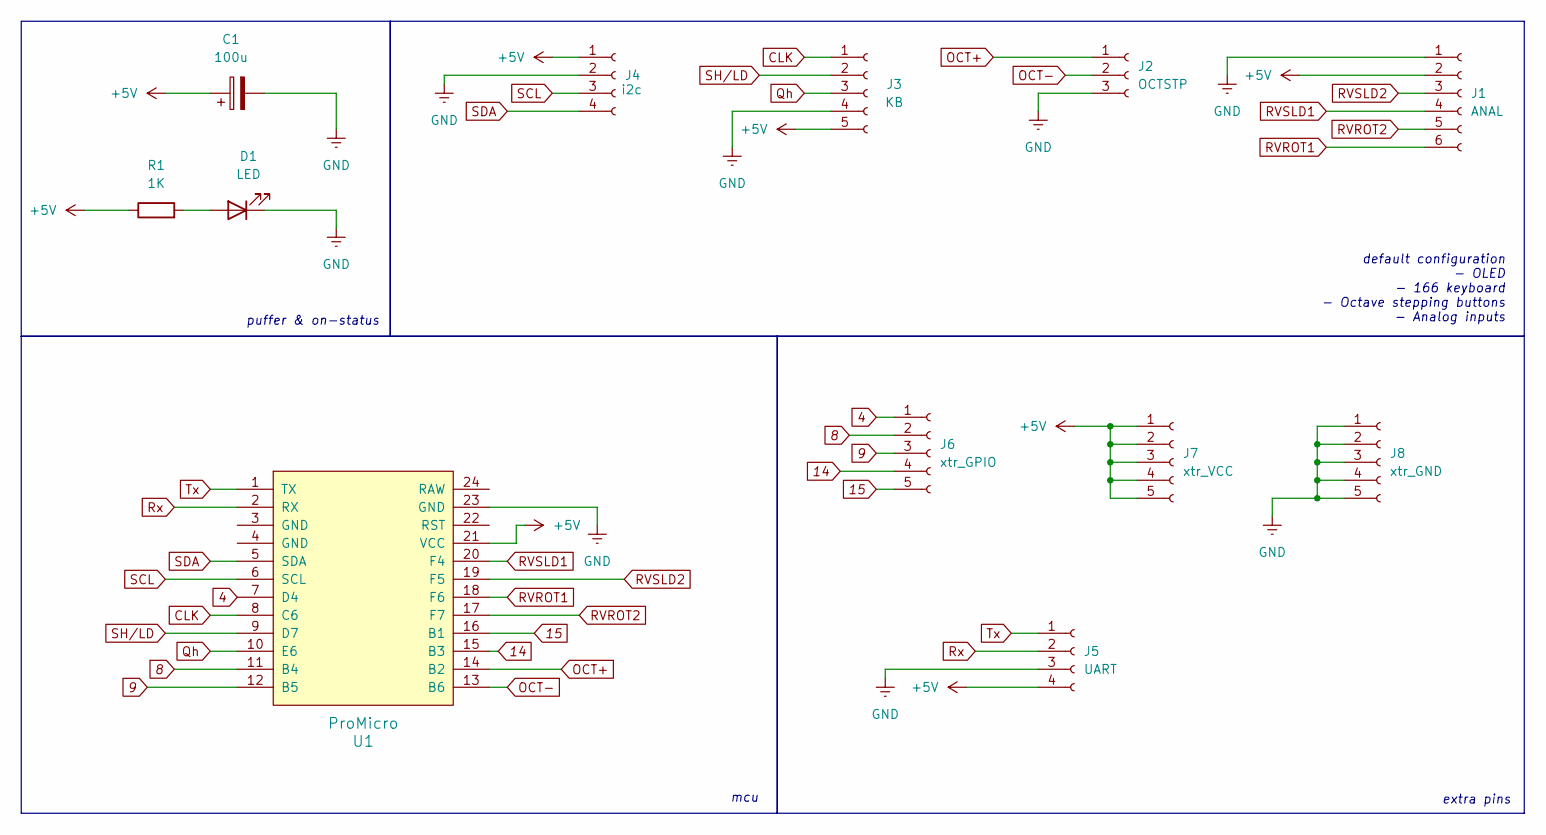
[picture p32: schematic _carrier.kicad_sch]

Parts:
C1: 100u; CP_Radial_D10.0mm_P5.00mm
D1: LED; LED_D5.0mm
J1: ANAL; PinSocket_1x06_P2.54mm_Vertical
J2: OCTSTP; PinSocket_1x03_P2.54mm_Vertical
J3: KB; PinSocket_1x05_P2.54mm_Vertical
J4: i2c; PinSocket_1x04_P2.54mm_Vertical
J5: UART; PinSocket_1x04_P2.54mm_Vertical
J6: xtr_GPIO; PinSocket_1x05_P2.54mm_Vertical
J7: xtr_VCC; PinSocket_1x05_P2.54mm_Vertical
J8: xtr_GND; PinSocket_1x05_P2.54mm_Vertical
R1: 1K; R_Axial_DIN0309_L9.0mm_D3.2mm_P12.70mm_Horizontal
U1: ProMicro

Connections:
4: J6.1, U1.7 (D4)
8: J6.2, U1.11 (B4)
9: J6.3, U1.12 (B5)
14: J6.4, U1.15 (B3)
15: J6.5, U1.16 (B1)
+5V: C1.1, J1.2, J3.5, J4.1, J5.4, J7.1, J7.2, J7.3, J7.4, J7.5, R1.1, U1.21 (VCC)
CLK: J3.1, U1.8 (C6)
GND: C1.2, D1.1 (K), J1.1, J2.3, J3.4, J4.2, J5.3, J8.1, J8.2, J8.3, J8.4, J8.5, U1.23 (GND)
unnamed: D1.2 (A), R1.2
OCT+: J2.1, U1.14 (B2)
OCT-: J2.2, U1.13 (B6)
Qh: J3.3, U1.10 (E6)
RVROT1: J1.6, U1.18 (F6)
RVROT2: J1.5, U1.17 (F7)
RVSLD1: J1.4, U1.20 (F4)
RVSLD2: J1.3, U1.19 (F5)
Rx: J5.2, U1.2 (RX)
SCL: J4.3, U1.6 (SCL)
SDA: J4.4, U1.5 (SDA)
SH/LD: J3.2, U1.9 (D7)
Tx: J5.1, U1.1 (TX)

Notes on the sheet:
default configuration - OLED - 166 keyboard - Octave stepping buttons - Analog inputs
mcu
extra pins
puffer & on-status

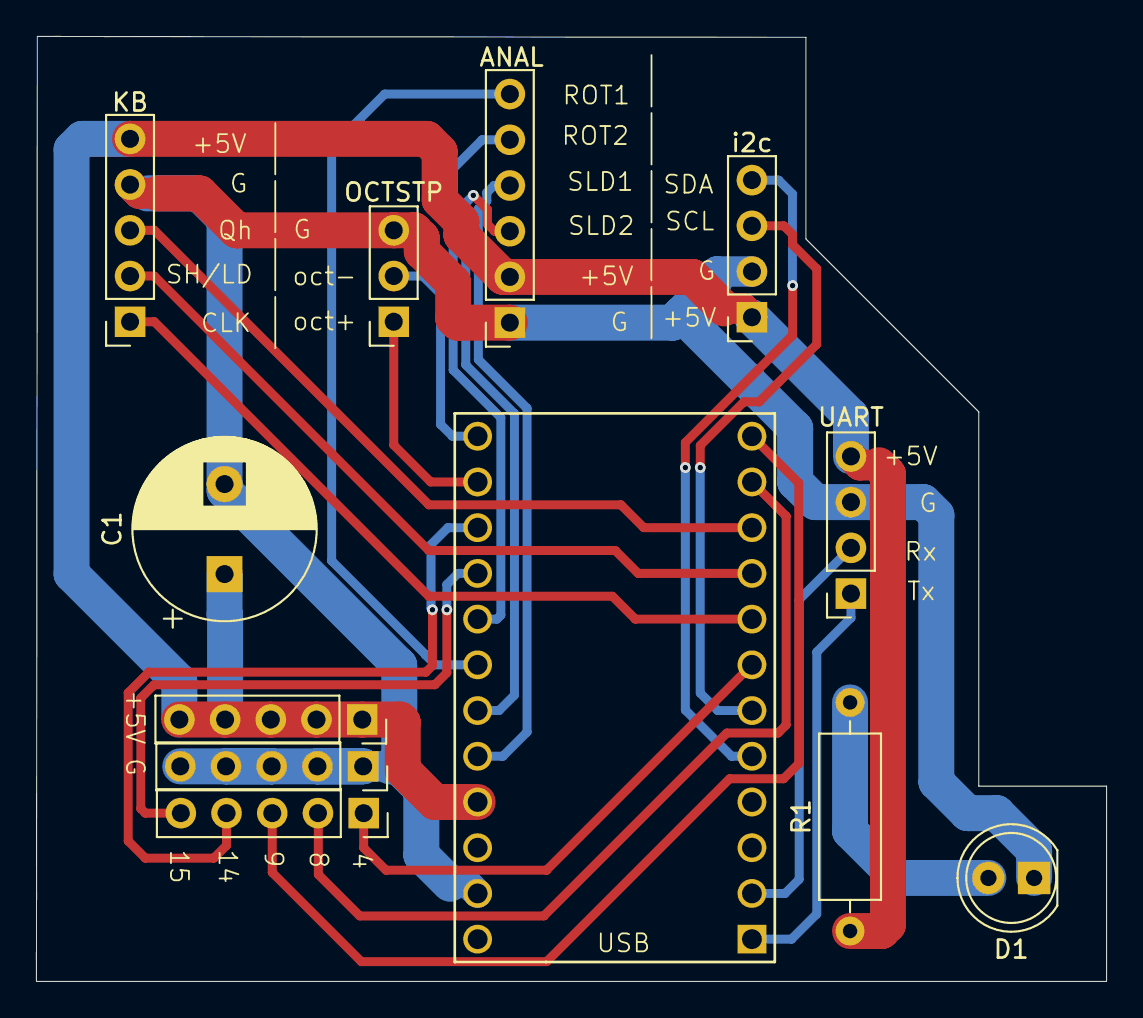
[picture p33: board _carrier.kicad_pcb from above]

Board: 2 copper layers, 59.5 x 52.5 mm, 12 parts (0 on the bottom side), 21 nets.

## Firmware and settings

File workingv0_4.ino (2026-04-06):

#include "MIDIUSB.h"

const int NUM_KEYS = 12;

const int NUM_POTS = 1;

const byte keyPins[NUM_KEYS] =   { 2,  3,  4,  5,  6,  7,  8,  9,  21, 20, 19, 15 };
const byte midiNotes[NUM_KEYS] = { 48, 50, 51, 52, 53, 55, 54, 57, 49, 56, 59, 58 };
//                                 C   D   D#  E   F   G   F#  A   C#  G#  B   A#

const int potPins[NUM_POTS] = { A0 };

const int octKeyPins[2] = { 10, 16 };

// 48 = middle C

// update when key is pressed or released
int lastKeyState[NUM_KEYS] = { 0, 0, 0, 0, 0, 0, 0, 0, 0, 0, 0, 0 };

int lastPotState[NUM_POTS] = { 127 };

int lastOctKeyState[2] = { 0, 0 };

byte octave = 0;

void noteOn(byte channel, byte pitch, byte velocity) {
  midiEventPacket_t noteOn = { 0x09, 0x90 | channel, pitch, velocity };
  MidiUSB.sendMIDI(noteOn);
}

void noteOff(byte channel, byte pitch, byte velocity) {
  midiEventPacket_t noteOff = { 0x08, 0x80 | channel, pitch, velocity };
  MidiUSB.sendMIDI(noteOff);
}

void controlChange(byte channel, byte control, byte value) {
  midiEventPacket_t event = { 0x0B, 0xB0 | channel, control, value };
  MidiUSB.sendMIDI(event);
}

void sendHiResCC(byte channel, byte control, int value) {
  byte lsb = value & 0x7F;
  byte msb = (value >> 7) & 0x7F;

  controlChange(channel, control, msb);
  controlChange(channel, control + 32, lsb);
}

void setup() {
  Serial.begin(115200);

  for (int i = 0; i < NUM_KEYS; i++) {
    pinMode(keyPins[i], INPUT_PULLUP);
    digitalWrite(i, 1);
  }

  pinMode(10, INPUT);
  pinMode(16, INPUT);
}

int num = 0;

void loop() {

  bool anyPotChanged = false;
  bool anyKeyChanged = false;  // A flag to tell us if we need to flush the USB

  // Loop through all 12 keys
  for (int i = 0; i < NUM_KEYS; i++) {
    int currentState = digitalRead(keyPins[i]);

    // Check if this specific key changed state
    if (currentState != lastKeyState[i]) {
      Serial.print(i);
      Serial.println(". key changed");
      Serial.print("which is pin ");
      Serial.println(keyPins[i]);
      int pitchValue = midiNotes[i] + (octave * 12);

      if (currentState == 0) {
        // Key was PRESSED

        noteOn(0, pitchValue, 64);
        //Serial.print(i); Serial.println(". on");
        Serial.print("sending ");
        Serial.println(midiNotes[i]);
      } else {
        // Key was RELEASED
        noteOff(0, pitchValue, 64);
        //Serial.print(i); Serial.println(". off");
      }

      lastKeyState[i] = currentState;

      anyKeyChanged = true;
    }

    if (anyKeyChanged) {

      MidiUSB.flush();
      //delay(15);
    }
  }

  // same as key for pots
  for (int i = 0; i < NUM_POTS; i++) {

    int currentPotState = analogRead(potPins[i]);

    if (abs(currentPotState - lastPotState[i]) >= 2) {
      Serial.println(currentPotState);
      int midiValue = map(currentPotState, 0, 1023, 0, 16383);  // scale up 10 bit analog input to 14 bit for MIDI CC message MSB and LSB
      Serial.println(midiValue);
      sendHiResCC(0, 16, midiValue);
      lastPotState[i] = currentPotState;

      anyPotChanged = 1;
    }
  }

  if (anyPotChanged) {
    MidiUSB.flush();
    //delay(2);  // A single 15ms debounce delay covers all keys at once
  }

  for (int i = 0; i < 2; i++) {
    int currentState = digitalRead(octKeyPins[i]);
    if (currentState != lastOctKeyState[i]) {
      lastOctKeyState[i] = currentState;
      if (currentState == 1) {
        if (i == 0 && octave > -4) {
          octave -= 1;
          Serial.println("Decreasing octave");
        } else {
          if (i == 1 && octave < 6) {
            octave += 1;
            Serial.println("Increasing octave");
          }
        }
        Serial.print("Octave: ");
        Serial.println(octave);
      }
    }
  }
}

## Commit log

2026-04-26 SCHEMATIC 2026-04-26
    KiCAD 8.0-ban készített projekt
    - kapcsolási rajz a 2 oktávos billentyűzet nélkül rövid leírásokkal. (ANGOL, ellenőrizni kell)
    - exportált pdf
    [midi_controller_atmega32u4.kicad_pcb, midi_controller_atmega32u4.kicad_sch]
2026-04-26 dark schematic export 2026-04-26
2026-04-26 SCHEMATIC UPDATE 2026-04-27
    - kapcsolási rajz frissítve (keyboard)
    [midi_controller_atmega32u4.kicad_sch]
2026-05-16 Rename Screenshot 2026-05-16 at 21.01.59.png to Schematic
2026-05-23 Rename 20260523_023652.mp4 to Keyboard pitch wheel octave demo.mp4
2026-05-29 Update README.md
    Csak legyen már akkor benne az UART gecixd
2026-05-29 1st pcb plan devboard like
    1:30 AM GECIII
    [_carrier.kicad_pcb, _carrier.kicad_sch]
2026-05-30 keyboard pcb
    [_carrier-B_Cu.gbr, _carrier-B_Mask.gbr, _carrier-B_Paste.gbr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]
2026-05-30 octstep schematic and pcb
    [_octstp-B_Cu.gbr, _octstp-B_Mask.gbr, _octstp-B_Paste.gbr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]
2026-05-30 fuuuuu sok minden, majd csekkold
    [_anal-B_Cu.gbr, _anal-B_Mask.gbr, _anal-B_Paste.gbr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]
2026-06-07 missed pushes
    [mkoa_combinedpcb.kicad_pcb]
